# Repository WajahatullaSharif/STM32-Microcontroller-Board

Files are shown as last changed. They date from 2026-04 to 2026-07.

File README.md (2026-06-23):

# DeskNode-F4: Desk Automation Node

**DeskNode-F4** is an intelligent, high-current desk automation controller designed to eliminate phantom standby power and manage workspace environments dynamically. Built around the **STM32F407VGT6** microcontroller, the board intercepts host sleep/wake signals to automatically switch power rails for major workspace appliances and custom peripherals.

---

## 📊 System Architecture Block Diagram

```mermaid
graph TD
    %% Styling Configuration
    classDef mcu fill:#1b4d3e,stroke:#333,stroke-width:1.5px,color:#fff;
    classDef power fill:#d4af37,stroke:#333,stroke-width:1px,color:#000;
    classDef peripheral fill:#e1f5fe,stroke:#0288d1,stroke-width:1px,color:#000;
    classDef external fill:#f5f5f5,stroke:#616161,stroke-width:1px,color:#000;

    %% Central PCBA
    subgraph DeskNode_F4 [DeskNode-F4]
        DEBUGGER[STM32F103 Debugger]:::mcu
        MCU[STM32F407 MCU]:::mcu
        ETH[DP83826 PHY]:::peripheral
        LED_DRV[LED Driver ~5A]:::peripheral
        SENSE[Shunt + Op-Amp]:::peripheral
        RELAY_DRV[Relay Drivers]:::peripheral
    end

    %% Left-Side Power Inputs
    USB_OTG[OTG USB]:::power
    USB_DEB[Debug USB]:::power

    %% External Systems
    subgraph Laptop_Host [Laptop Host]
        LAPTOP[Laptop PC]:::external
    end

    subgraph AC_Loads [AC Mains Loads]
        LOADS[Monitors/Speakers/Other]:::external
    end

    %% Invisible spacer layout trick to push AC Loads down
    Laptop_Host ~~~ AC_Loads

    %% Left-Side Power Routing Layout
    USB_OTG -->|Power Input| MCU
    USB_DEB --> DEBUGGER
    DEBUGGER -->|Debug/Power| MCU
    
    %% Right-Side Power Routing Layout
    12V[12V Adaptor]:::power -->|DC Jack| LED_DRV

    %% Communication & Interface Links
    LAPTOP -->|Ethernet Link| ETH
    ETH <-->|RMII| MCU
    LAPTOP -->|USB CDC| MCU

    %% Output Paths
    MCU -->|PWM| LED_DRV -->|JST| STRIP[RGB LED Strip]:::external
    STRIP -->|Return| SENSE -->|Analog| MCU
    MCU -->|GPIO| RELAY_DRV -->|Control| AC_Loads
```

---

## 🛠️ System Architecture Overview

The core of the system is a custom **4-layer PCB** configured with a high-integrity stackup (**Signal / GND / Power / Signal**) to isolate sensitive analog paths from high-power switching transients.

### Onboard Hardware Features
* **Microcontroller:** STM32F407 ARM Cortex-M4 operating with a high-performance clock tree to coordinate networking, USB stacks, and deterministic control loops.
* **Onboard Debugger:** Integrated STM32F103-based DAP-Link. This permits single-cable firmware flashing and debugging directly over the `Debug USB` port without requiring external programmers.
* **Networking Subsystem:** DP83826 Physical Layer (PHY) transceiver linked to the MCU via a low-pin-count **RMII (Reduced Media Independent Interface)** bus. It provides a dedicated pipeline for sending continuous telemetry and log metrics to an external server or logging application.
* **Dual Power Inputs:** Flexible bus powering options allow the system logic to run entirely off the `Debugger USB (5V)` line or the primary `OTG USB (5V)` interface.

### Peripheral Control & Telemetry Loops
* **High-Current LED Driver:** A dedicated ~5A PWM driver stage capable of dimming and driving dense RGB LED strips utilized for monitor backlighting.
* **Current Telemetry (Shunt + Op-Amp):** A low-side inline current shunt paired with a precision operational amplifier provides analog current sensing feedback directly to the MCU's internal ADC. This ensures overload protection and active power calculation.
* **Relay Driver Array:** Low-voltage GPIO pins drive transistor/optocoupler stages to switch external heavy-duty AC relay modules safely.

---

## 🔄 Sequence of Operation

The system functions on a deterministic host-state monitoring loop via a virtual COM port over USB:

| Laptop State | USB CDC Pipeline | DeskNode-F4 Action |
| :--- | :--- | :--- |
| **Laptop Wakes** | Sends `"WAKE"` Token | 1. Latches AC Relays **ON** <br> 2. Ramps up Monitor LED Strip and Speakers |
| **Laptop Sleeps** | CDC Connection Drops | 1. Unlatches AC Relays **OFF** <br> 2. Cuts LED Strip Power |

### 1. The Wake Sequence (Power-On)
1. The host laptop wakes from standby or a sleep state.
2. An automation daemon running on the host detects the system state change and establishes a **USB CDC (Communications Device Class)** virtual serial connection.
3. The host transmits a configuration/activation token to the `DeskNode-F4` over USB.
4. The MCU immediately asserts its control GPIOs:
    * **Relay Output Pins** transition to high, latching the AC relay modules to deliver mains power simultaneously to **Monitor 1, Monitor 2, the Laptop Power Adaptor, and the Home Theatre System**.
    * **PWM Driver** initializes to ramp up the RGB backlight strip to the user's preferred brightness level via the onboard JST connection.

### 2. Continuous Monitoring State
* While active, the board uses the **DP83826 Ethernet PHY** to broadcast runtime diagnostics (uptime, temperature, and power drawing conditions) back to the laptop's logging software.
* The internal ADC continuously updates using the operational amplifier feedback loop across the shunt resistor to verify the current draw of the 5A LED string remains within a safe operating safe area (SOA).

### 3. The Sleep Sequence (Zero-Standby Power)
1. The host laptop enters a low-power sleep mode or is shut down.
2. The active USB CDC bus is dropped or broadcasts a graceful shutdown command packet.
3. Upon detecting the drop in the USB connection state, the `STM32F407` executes an emergency environment teardown:
    * All **GPIO Relay Driver lines** drop low, physically disconnecting the mains AC power lines. This drops the idle standby current consumption of the entire desk setup (monitors, sound systems, bricks) down to **absolute zero**.
    * The LED driver PWM is pulled to a 0% duty cycle, turning off the backlight completely.
    * The board drops into a low-power listening loop, drawing minimal parasitic power through the connected USB line until the next wake event.

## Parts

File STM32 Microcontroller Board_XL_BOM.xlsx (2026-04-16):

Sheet: BOM
Sr.No | Ref Des | Qty | Value | MPN | Make | Alternates/Substitutes | Make | Total Cost
1 | C1, C3, C9, C10
2 | C2, C4, C8
3 | C5
4 | C6, C7
5 | D1
6 | D2
7 | D3
8 | D4
9 | D5
10 | U1 | 1 | LOW COST ENET PHY INDUSTRIAL | DP83826IRHBR | Texas Instruments
11 | U2 | 3 | MOSFETs MOSFT 5.0A 29mOhm 30V 2.5V drv capable | IRLML6344TRPBF | Infineon Technologies
12 | R1, R5, R6, R14
13 | R2
14 | R3
15 | R4
16 | R7, R15
17 | R8, R16
18 | R9, R17
19 | R10, R18
20 | R11, R19
21 | R12, R20
22 | R13, R21, R23, R24
23 | R22
24 | R25, R26, R27, R28
25 | J1, J2
26 | J3
27 | X1 | 1 | CONN JACK 1PORT PCB | RJMG1S8008101BR | Amphenol ICC (Commercial Products)
28 | X2
 |  |  |  |  |  |  | Shipping cost
 |  |  |  |  |  |  | Total cost | ₹0.00

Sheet: Comparison
LED MOSFETs | Make | Vds | Id | Vgs(th) max | Rds ON @ 3.3V | Qc | Pd | Rja | Td On | Td Off | Tr | Tf | Cost
IRLML6344TRPBF | Infenion | 30V | 5A | 1.1V | 34mohm | 6.8nC | 1.3W | 100 C/W | 4.2ns | 22ns | 5.6ns | 9.1ns | ₹46
DMN3053L | Diodes | 30V | 4A | 1.4V | 52mohm | 7.3nC | 0.76W | 100 C/W | 2ns | 152ns | 5.5ns | 32ns | ₹50
DMN3065LW-7 | Diodes | 30V | 4A | 1.5V | 75mohm | 5.5nC | 0.77W | 162 C/W | 1.9ns | 10.3ns | 1.6ns | 2ns | ₹43
DMG3402L-7 | Diodes | 30V | 4A | 1.4V | 75mohm | 5.5nC | 1.4W | 90 C/W | 1.9ns | 10.3ns | 1.6ns | 2ns | ₹21
DMN3150L-7 | Diodes | 30V | 3.8A | 1.4V | 90mohm | 8.2nC | 1.4W | 90 C/W | 1.14ns | 15ns | 3.5ns | 3.3ns | ₹38

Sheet: Requirements
Current sensing for LED Drivers with internal ADC |  |  | LED strip connector
Use OPAMP TLV9001 with non inverting amplifier config
Shunt resistor | 20mohm, >=3W(5W preferred)
Current Limit | 5A | Vshunt = 100mV
Fault Current | 10A | Vshunt = 200mV
Map | 0 to 10A | 0 to 2V
Gain | 10x
Filtering | 2nd order LPF
Values | R=2.2kohm, C=0.47nF
230V Power Control
Use ULN2803CDWR
COM->VDD for SSR, NC for Mech relay
12V adaptor for LED and relay control
Board Power |  |  | STLINK_VBUS ──|>|──┐
Diode OR USB FS and Debugger USB Vbus |  |  | +5V_BOARD ── LDO ── 3V3 (STM32)
Use low-Vf Schottky: SS14 / PMEG2010 / BAT54S (dual) - ≥1 A rating (USB + LED logic load) |  |  | USB_FS_VBUS ──|>|──┘
12V only for relays and LED |  |  | EXT_5V In/ Out ──────┘
OTG_FS_PowerSwitchOn (PH5)
Leave PH5 unconnected. Or pull it down weakly |  |  | 12V_ADAPTER ────────────► LED MOSFETs
Do NOT connect PA9 (VBUS sense) through diode. Connect directly |  |  | └─────────────► SSR Relay board

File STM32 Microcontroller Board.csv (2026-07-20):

Reference | Qty | Value | Description | Footprint | MPN
C1,C4,C7,C8,C9,C10,C11,C12,C13,C16,C17,C19,C25,C26,C29,C30,C31,C33,C35,C42,C50 | 21 | 0.1uF | CAP CER 0.1UF 10V X7R 0402 | Capacitor_SMD:C_0402_1005Metric | GRM155R71A104KA01D
C2,C5 | 2 | 2.2uF | CAP CER 2.2UF 10V X7R 0603 | Capacitor_SMD:C_0603_1608Metric | CL10B225KP8NNNC
C3,C6,C27,C36,C43,C51 | 6 | 1uF | CAP CER 1UF 10V X7R 0603 | Capacitor_SMD:C_0603_1608Metric | CL10B105KP8NNNC
C14,C28 | 2 | 4.7uF | CAP CER 4.7UF 16V X7R 0805 | Capacitor_SMD:C_0805_2012Metric | GRM21BR71C475KE51L
C15,C20 | 2 | 10uF | CAP CER 10UF 16V X7R 0805 | Capacitor_SMD:C_0805_2012Metric | CL21B106KOQNNNE
C18 | 1 | 1nF | CAP CER 1000PF 16V X7R 0603 | Capacitor_SMD:C_0603_1608Metric | C0603C102K4RACTU
C21,C24,C34,C41 | 4 | 10nF | CAP CER 10000PF 25V X7R 0402 | Capacitor_SMD:C_0402_1005Metric | GRM155R71E103KA01D
C22,C23,C38,C39 | 4 | 27pF | CAP CER 27PF 50V C0G/NP0 0603 | Capacitor_SMD:C_0603_1608Metric | CL10C270JB8NNNC
C32 | 1 | 1nF | CAP CER 1000PF 2KV X7R 1206 | Capacitor_SMD:C_1206_3216Metric | CC1206KKX7RDBB102
C37 | 1 | 2nF | CAP CER 2000PF 50V C0G/NP0 0603 | Capacitor_SMD:C_0603_1608Metric | GRM1885C1H202JA01D
C40,C44 | 2 | 10uF | CAP CER 10UF 10V X7R 0805 | Capacitor_SMD:C_0805_2012Metric | GRM21BR71A106KA73L
C45 | 1 | 1uF | CAP CER 1UF 50V X7R 0603 | Capacitor_SMD:C_0603_1608Metric | CC0603KRX7R9BB105
C46 | 1 | 0.1uF | CAP CER 0.1UF 50V X7R 0603 | Capacitor_SMD:C_0603_1608Metric | C0603C104K5RACTU
C47 | 1 | 680uF | CAP ALUM 680UF 20% 25V SMD | footprints:UCL1E681MNL1GS | UCL1E681MNL1GS
C48,C49 | 2 | 0.47uF | CAP CER 0.47UF 25V X7R 0603 | Capacitor_SMD:C_0603_1608Metric | CL10B474KA8NFNC
D1 | 1 | 3.3V | 300mW Zener Diode, SOD-323F | Diode_SMD:D_SOD-323F | MM3Z3V3T1G
D2,D3,D9 | 3 | Green LED | LED GREEN CLEAR CHIP SMD | LED_SMD:LED_0805_2012Metric | APT2012CGCK
D4,D13 | 2 | Blue LED | LED BLUE CLEAR 2SMD | LED_SMD:LED_0805_2012Metric | APT2012LVBC/D
D5,D11 | 2 | Yellow LED | LED YELLOW CLEAR CHIP SMD | LED_SMD:LED_0805_2012Metric | APT2012SYCK
D6 | 1 | Red LED | LED RED CLEAR CHIP SMD | LED_SMD:LED_0805_2012Metric | APT2012SURCK
D7 | 1 | LTST-E682KRKGWT | LED GREEN/RED DIFFUSED 4PLCC SMD | footprints:LTSTE683RGBW | LTST-E682KRKGWT
D8,D14 | 2 | LSM115JE3 | DIODE SCHOTTKY 15V 1A DO214BA | Diode_SMD:D_SMB | LSM115JE3-TR13
D10 | 1 | SP1004U-ULC-04UTG | ESD Protection Diodes / TVS Diodes 5V .2pF 20kV 4CH | footprints:ESD8104MUTAG | SP1004U-ULC-04UTG
D12 | 1 | SMBJ15CA | TVS DIODE 15VWM 24.4VC DO214AA | footprints:SMBJ15A | SMBJ15CA
D15 | 1 | SMBJ15A | Littelfuse SMBJ15A, Uni-Directional TVS Diode, 600W, 2-Pin DO-214AA | footprints:SMBJ15A
D16,D17,D18 | 3 | SMF15A | 200W unidirectional Transil Transient Voltage Suppressor, 15Vrwm, SMF | Diode_SMD:D_SMF | SMF15A
F1,F3 | 2 | Polyfuse | PTC RESET FUSE 6V 750MA 1206 | Fuse:Fuse_1206_3216Metric | NANOSMDC075F-2
F2 | 1 | Polyfuse | PTC RESET FUSE 6.0A 16V 2920 | footprints:Fuse_2920_7451Metric | 2920L600/16MR
FB1,FB2 | 2 | FerriteBead | FERRITE BEAD 600 OHM 0603 1LN | Inductor_SMD:L_0603_1608Metric | MPZ1608S601ATA00
H1,H2,H3,H4 | 4 | MountingHole | Mounting Hole without connection | MountingHole:MountingHole_3.2mm_M3_Pad
J1 | 1 | F407 SWD | Generic connector, single row, 01x06, script generated | Connector_PinHeader_2.54mm:PinHeader_1x06_P2.54mm_Vertical
J2 | 1 | GPIO | Generic connector, double row, 02x09, odd/even pin numbering scheme (row 1 odd numbers, row 2 even numbers), script generated (kicad-library-utils/schlib/autogen/connector/) | Connector_PinHeader_2.54mm:PinHeader_2x09_P2.54mm_Vertical
J3 | 1 | Conn_01x02_Pin | Generic connector, single row, 01x02, script generated | Connector_PinHeader_2.54mm:PinHeader_1x02_P2.54mm_Vertical
J4 | 1 | F103 SWD | Generic connector, single row, 01x06, script generated | Connector_PinHeader_2.54mm:PinHeader_1x06_P2.54mm_Vertical
J5,J10 | 2 | USB_B_Micro | MICRO B SKT, BOTTOM-SMT, R/A, 30 | footprints:USB_Micro-B_GCT_USB3076-30-A | USB3076-30-A
J6 | 1 | Ethernet | CONN JACK 1PORT PCB | footprints:AMPHENOL_RJMG1S8008101BR | RJMG1S8008101
J7 | 1 | 12V IN | DC Barrel Jack with an internal switch | Connector_BarrelJack:BarrelJack_Horizontal
J8 | 1 | 12V RGB LED | CONN HEADER R/A 4POS 3.96MM | footprints:B4PS-VH | B4PS-VH(LF)(SN)
J9 | 1 | Relay IO | Generic connector, double row, 02x05, odd/even pin numbering scheme (row 1 odd numbers, row 2 even numbers), script generated (kicad-library-utils/schlib/autogen/connector/) | Connector_PinHeader_2.54mm:PinHeader_2x05_P2.54mm_Vertical
Q1 | 1 | PMOS | MOSFET P-CH 30V 13A 8SOIC | Package_SO:SOIC-8_5.3x5.3mm_P1.27mm | FDS6679AZ
Q2,Q3,Q4 | 3 | NMOS | MOSFET N-CH 30V 5A MICRO3/SOT23 | Package_TO_SOT_SMD:SOT-23 | IRLML6344TRPBF
R1,R2,R4,R7,R25,R28,R32,R34,R36,R37,R39,R40,R42,R56,R57,R58,R59,R60,R61,R62,R63,R64 | 22 | 10k | RES 10K OHM 1% 1/10W 0603 | Resistor_SMD:R_0603_1608Metric | RC0603FR-0710KL
R3,R6,R10 | 3 | 330R | RES 330 OHM 1% 1/10W 0603 | Resistor_SMD:R_0603_1608Metric | RC0603FR-07330RL
R5,R46,R50,R53 | 4 | 100R | RES 100 OHM 1% 1/10W 0603 | Resistor_SMD:R_0603_1608Metric | RC0603FR-07100RL
R8 | 1 | 33k | RES 33K OHM 1% 1/10W 0603 | Resistor_SMD:R_0603_1608Metric | RC0603FR-0733KL
R9 | 1 | 82k | RES 82K OHM 1% 1/10W 0603 | Resistor_SMD:R_0603_1608Metric | RC0603FR-0782KL
R11,R21,R22 | 3 | 680R | RES 680 OHM 1% 1/10W 0603 | Resistor_SMD:R_0603_1608Metric | RC0603FR-07680RL
R12,R14,R30,R67 | 4 | 1k | RES 1K OHM 1% 1/10W 0603 | Resistor_SMD:R_0603_1608Metric | RC0603FR-071KL
R13,R26,R31 | 3 | 1.5k | RES 1.5K OHM 1% 1/10W 0603 | Resistor_SMD:R_0603_1608Metric | RC0603FR-071K5L
R15,R16 | 2 | 4K7 | RES 4.7K OHM 1% 1/10W 0603 | Resistor_SMD:R_0603_1608Metric | RC0603FR-074K7L
R17,R18,R19,R20,R27,R43,R44,R47,R52,R54,R68 | 11 | 100k | RES 100K OHM 1% 1/10W 0603 | Resistor_SMD:R_0603_1608Metric | RC0603FR-07100KL
R23,R24,R65,R66 | 4 | 22R | RES 22 OHM 1% 1/10W 0603 | Resistor_SMD:R_0603_1608Metric | RC0603FR-0722RL
R29 | 1 | 1M | RES 1M OHM 1% 1/10W 0603 | Resistor_SMD:R_0603_1608Metric | RC0603FR-071ML
R33 | 1 | 6.49k | RES 6.49K OHM 1% 1/10W 0603 | Resistor_SMD:R_0603_1608Metric | RC0603FR-076K49L
R35,R38,R41 | 3 | 2.49k | RES 2.49K OHM 1% 1/10W 0603 | Resistor_SMD:R_0603_1608Metric | RC0603FR-072K49L
R45 | 1 | 22.1k | RES 22.1K OHM 1% 1/10W 0603 | Resistor_SMD:R_0603_1608Metric | RC0603FR-0722K1L
R48 | 1 | 20m | RES 0.02 OHM 1% 3W 2512 | Resistor_SMD:R_2512_6332Metric | CRA2512-FZ-R020ELF
R49,R51 | 2 | 2.2k | RES 2.2K OHM 1% 1/10W 0603 | Resistor_SMD:R_0603_1608Metric | RC0603FR-072K2L
R55 | 1 | 90.9k | RES 90.9K OHM 1% 1/10W 0603 | Resistor_SMD:R_0603_1608Metric | RC0603FR-0790K9L
R69,R70,R71 | 3 | 0R | RES 0 OHM JUMPER 1/10W 0603 | Resistor_SMD:R_0603_1608Metric | RC0603JR-070RL
SW1,SW2,SW3,SW4,SW5,SW6 | 6 | SW_Push | SWITCH TACTILE SPST-NO 0.05A 12V | Button_Switch_SMD:SW_SPST_PTS645Sx43SMTR92 | PTS645SK50SMTR92 LFS
TP1 | 1 | BOOT0 | test point | TestPoint:TestPoint_Pad_D1.0mm
TP2 | 1 | NRST | test point | TestPoint:TestPoint_Pad_D1.0mm
TP3,TP4,TP5,TP7,TP8,TP9 | 6 | TestPoint | PC TEST POINT MINIATURE BLACK,test point | TestPoint:TestPoint_Keystone_5000-5004_Miniature | 5001
TP6 | 1 | RMII_REF_CLK | test point | TestPoint:TestPoint_Pad_D1.0mm
U1 | 1 | STM32F407VGTx | IC MCU 32BIT 1MB FLASH 100LQFP | Package_QFP:LQFP-100_14x14mm_P0.5mm | STM32F407VGT6
U2 | 1 | MCP1825S-3302E/EB | IC REG LINEAR 3.3V 500MA DDPAK-3 | footprints:DDPAK3_MC_MCH-L | MCP1825S-3302E/EB
U3 | 1 | STM32F103C8T6 | IC MCU 32BIT 64KB FLASH 48LQFP | footprints:QFP50P900X900X160-48N | STM32F103C8T6
U4,U8 | 2 | USBLC6-2 | TVS DIODE 5VWM 15VC SOT236 | Package_TO_SOT_SMD:SOT-23-6 | USBLC6-2SC6
U5 | 1 | DP83826IRHBR | LOW COST ENET PHY INDUSTRIAL | footprints:QFN50P500X500X100-33N-D | DP83826IRHBR
U6 | 1 | TLV9001TIDCKR | Low-power, Rail-to-Rail, 1MHz Operational Amplifier, SOT-353 | Package_TO_SOT_SMD:SOT-353_SC-70-5 | TLV9001TIDCKR
U7 | 1 | ULN2803CDWR | Bipolar (BJT) Transistor Array 8 NPN Darlington 50V 500mA Surface Mount 20-SOIC | footprints:ULN2803CDWR | ULN2803CDWR
Y1 | 1 | 8MHz | Two pin crystal | Crystal:Crystal_HC49-4H_Vertical | ECS-80-18-5PX-TR
Y2 | 1 | 25MHz | Four pin crystal, GND on pins 2 and 4 | footprints:ECS2501836B2CTYTR | ECS-250-18-36B2-CTY-TR

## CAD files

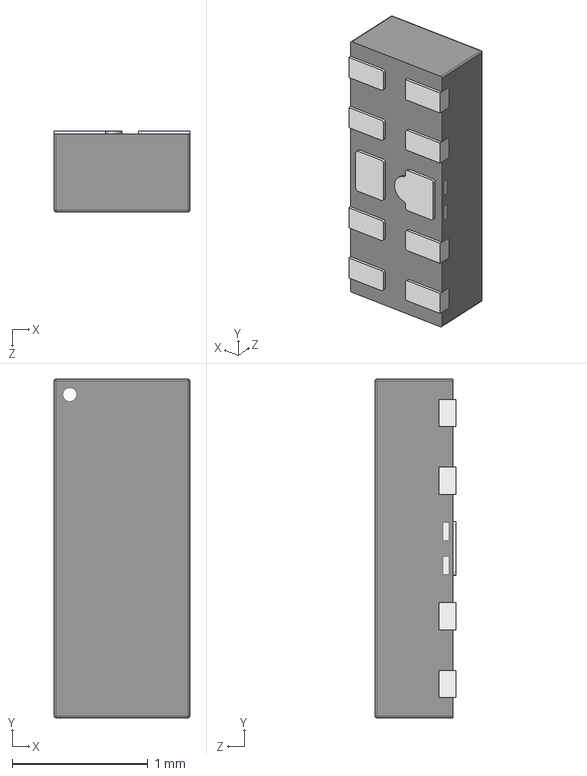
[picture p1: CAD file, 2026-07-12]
3dmodels/SP1004U-ULC-04UTG.stp
1.00 x 2.50 x 0.6 mm

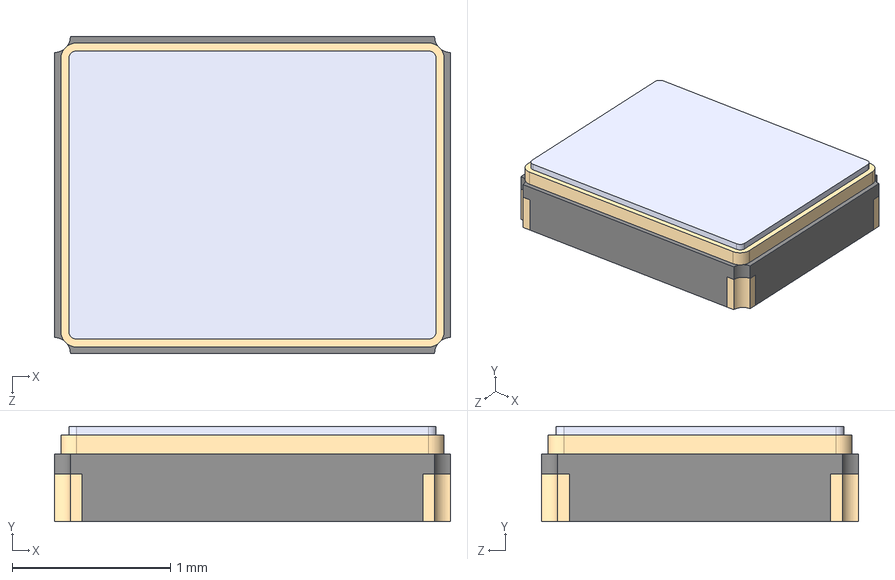
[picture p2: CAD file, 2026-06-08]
3dmodels/ECS-250-18-36B2-CTY-TR.stp
2.50 x 0.6 x 2.00 mm

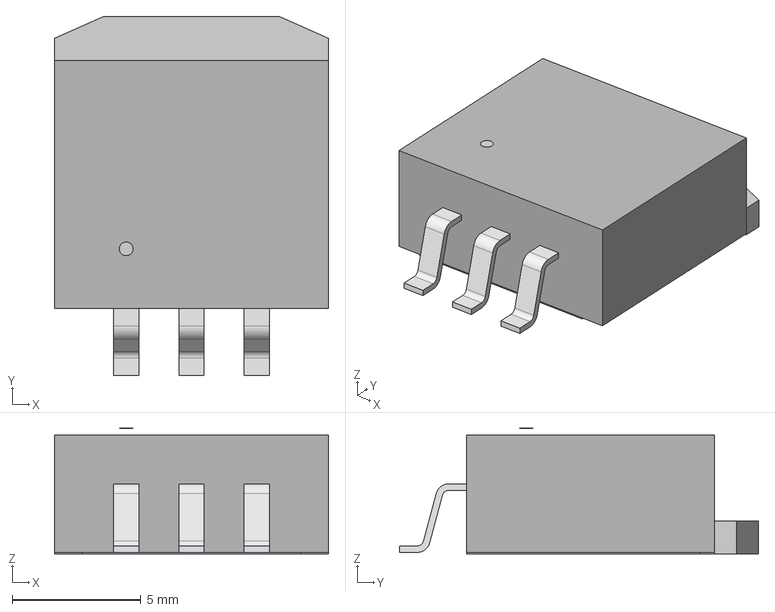
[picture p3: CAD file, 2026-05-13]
3dmodels/MCP1825S-3302EEB.step
10.7 x 14.0 x 4.88 mm

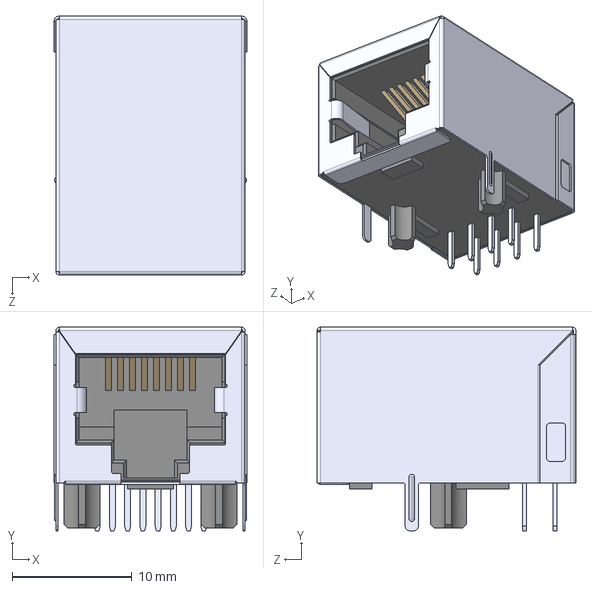
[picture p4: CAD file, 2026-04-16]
3dmodels/RJMG1S8008101BR--3DModel-STEP-418109.STEP
16.1 x 17.0 x 21.6 mm

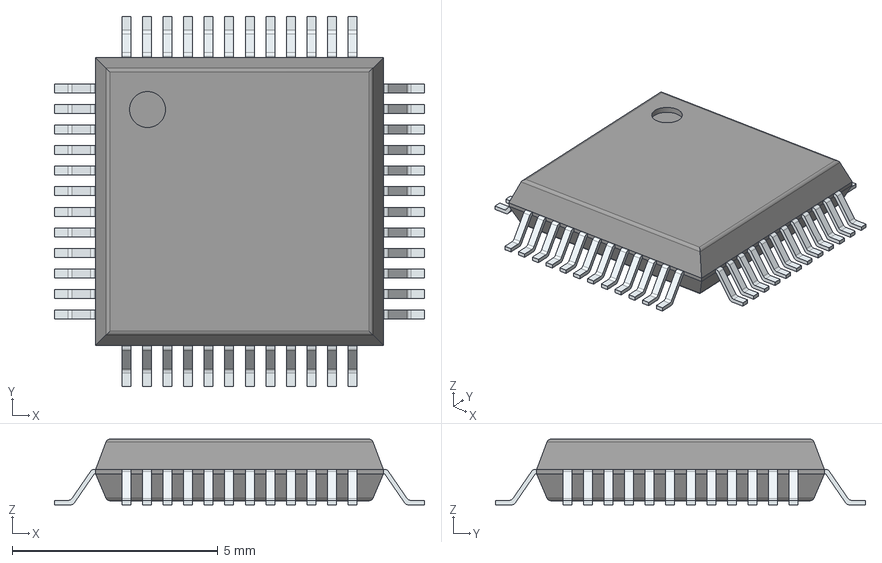
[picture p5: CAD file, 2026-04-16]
3dmodels/STM32F103C8T6.stp
9.00 x 9.00 x 1.60 mm
PinsArrayLR
PinsArrayTB

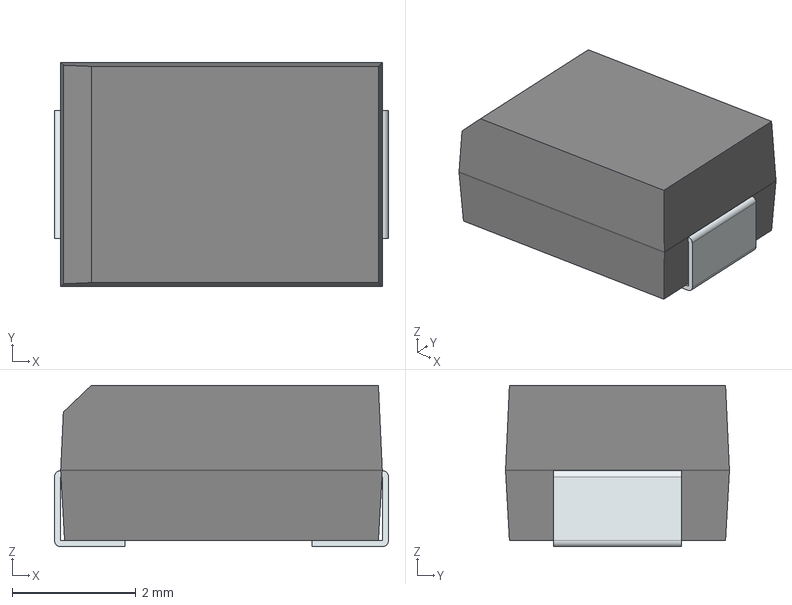
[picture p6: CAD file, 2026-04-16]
3dmodels/SMBJ15A.stp
5.40 x 3.62 x 2.61 mm
FilletPin1
FilletPin2

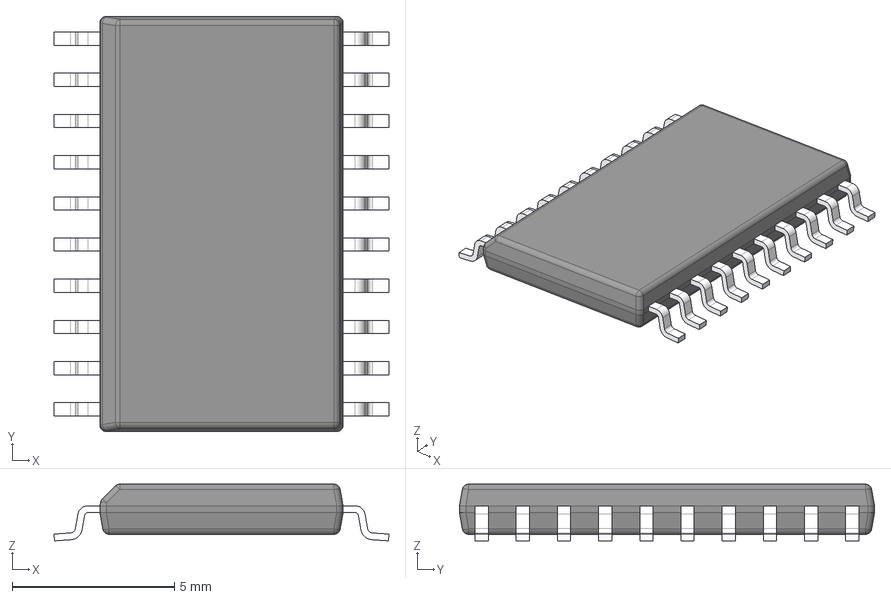
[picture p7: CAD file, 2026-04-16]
3dmodels/ULN2803CDWR.stp
10.3 x 12.8 x 1.75 mm
BODY-SO
LEAD-SO x 20
PIN1-ID

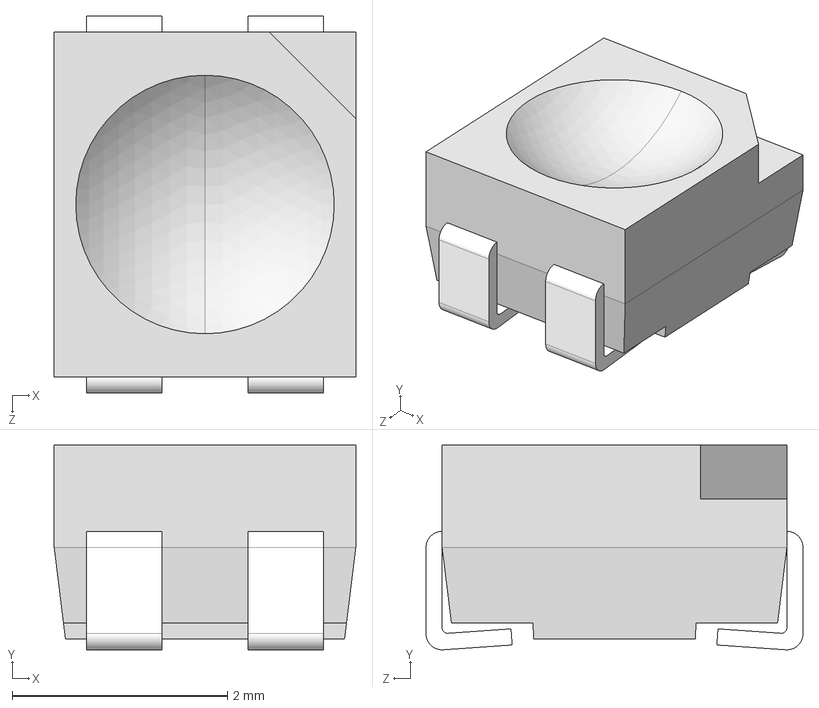
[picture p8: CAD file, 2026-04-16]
3dmodels/LTST-E682KRKGWT.stp
2.80 x 1.90 x 3.50 mm

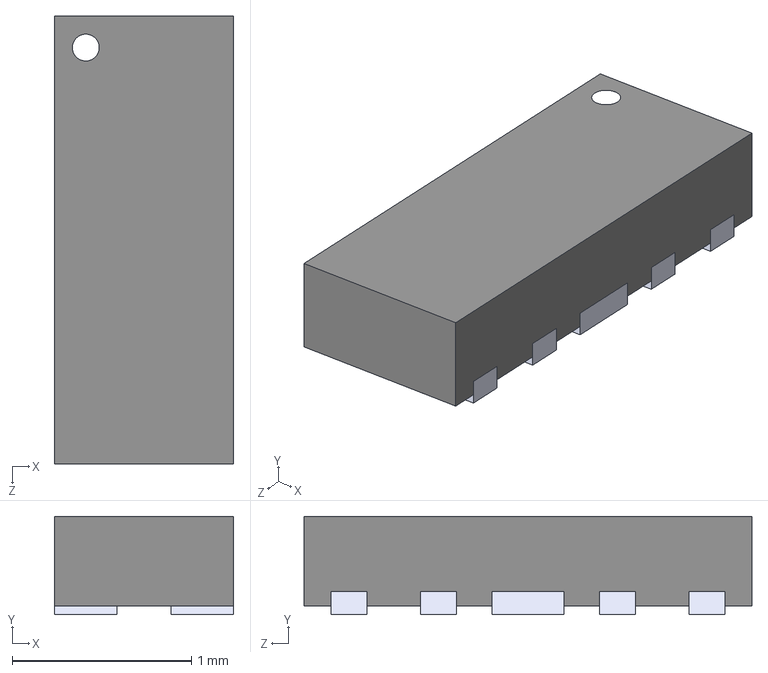
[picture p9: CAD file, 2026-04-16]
3dmodels/ESD7104MUTAG.STEP
1.00 x 0.55 x 2.50 mm

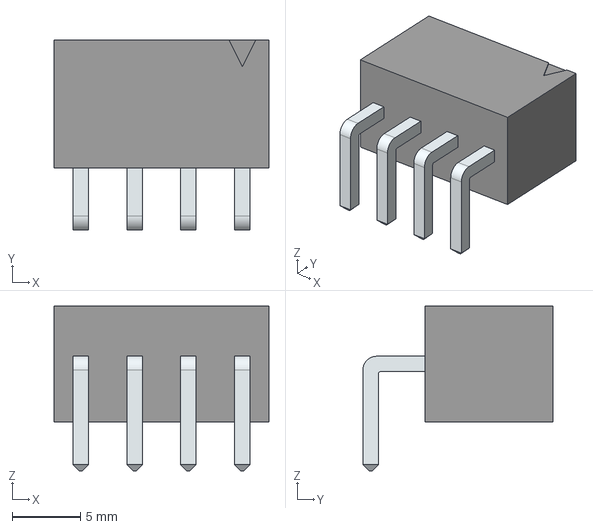
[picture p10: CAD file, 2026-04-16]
3dmodels/B4PS-VH_LF__SN_.stp
15.8 x 14.0 x 12.1 mm
LeadsArray

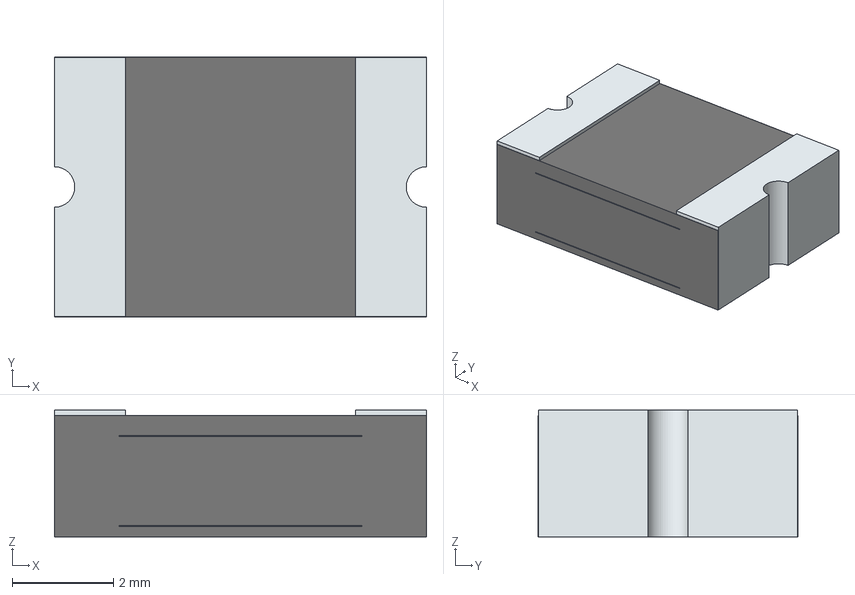
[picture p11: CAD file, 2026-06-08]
3dmodels/2920L600_24SLER.stp
7.35 x 5.14 x 2.50 mm
Rect6
Rect7
solidBody
Terminal

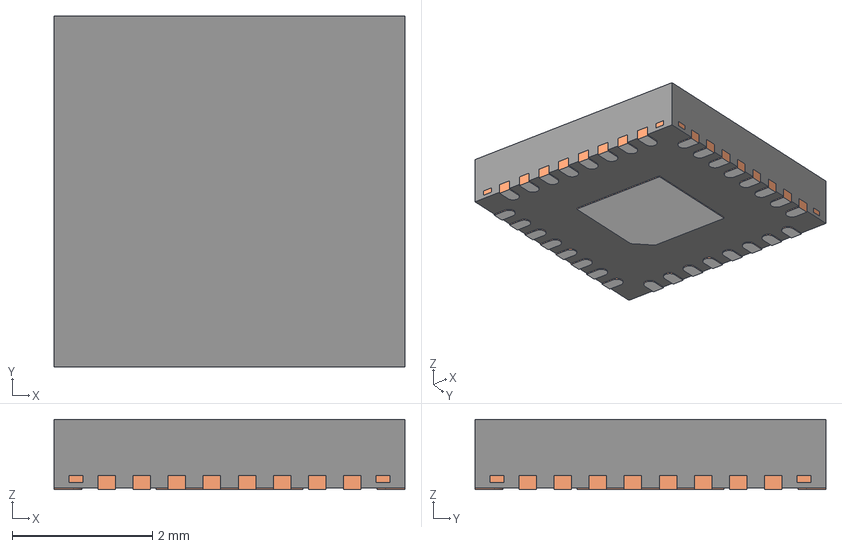
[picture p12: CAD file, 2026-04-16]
3dmodels/DP83826IRHBR.stp
5.00 x 5.00 x 1.00 mm
BODY-QFN
FRAME-RHB0032M
PIN1-ID

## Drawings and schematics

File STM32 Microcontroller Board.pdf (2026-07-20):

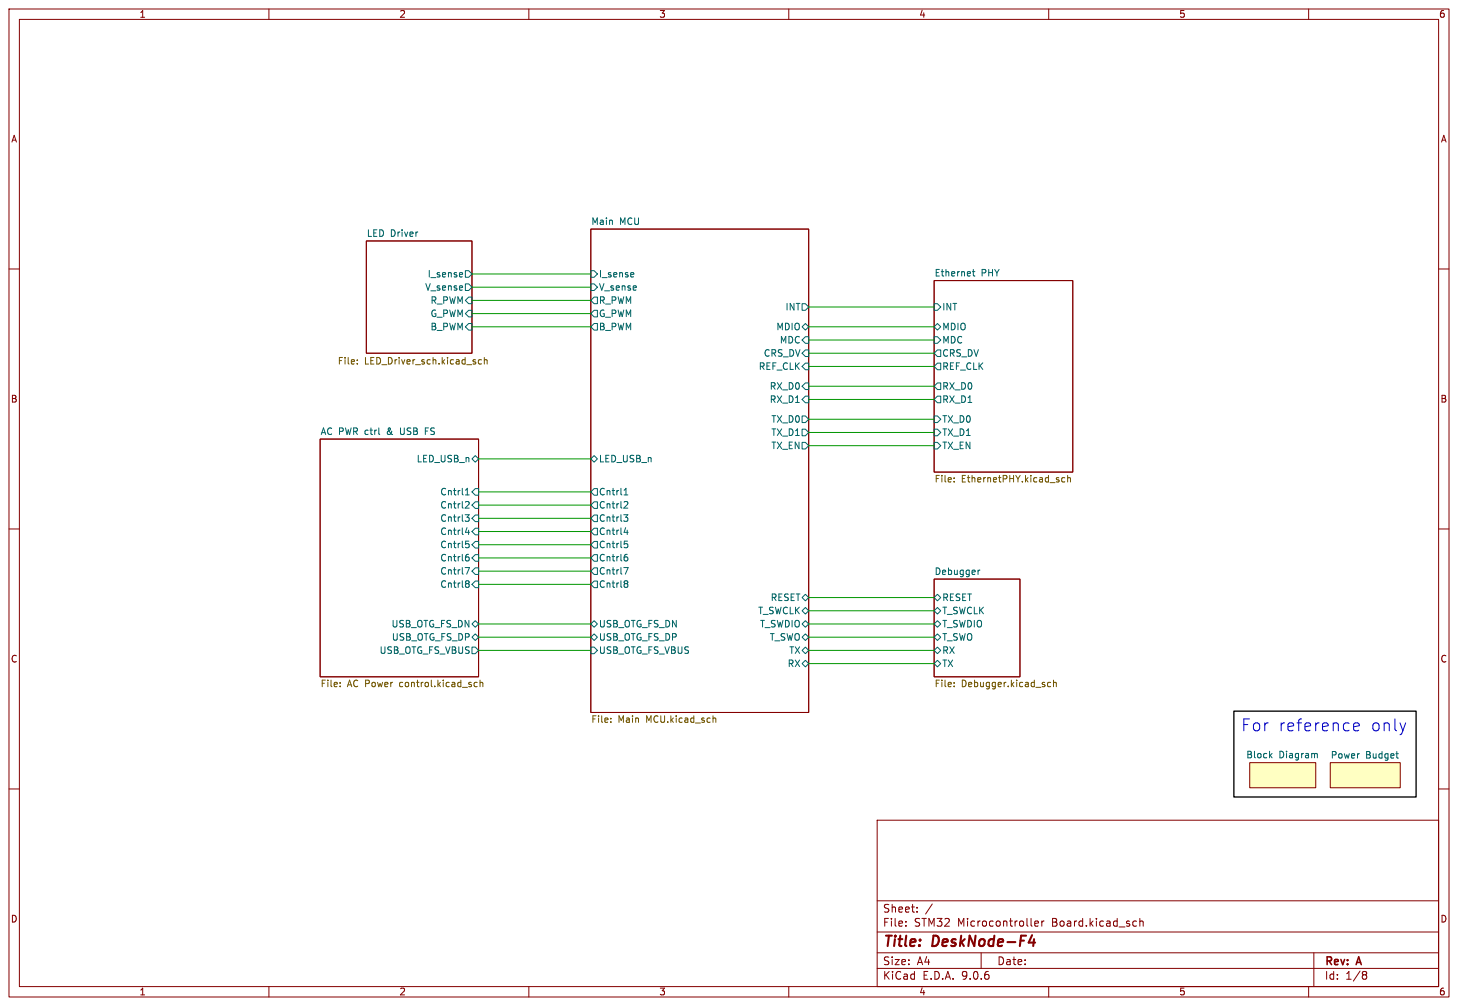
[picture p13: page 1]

AC PWR ctrl & USB FS

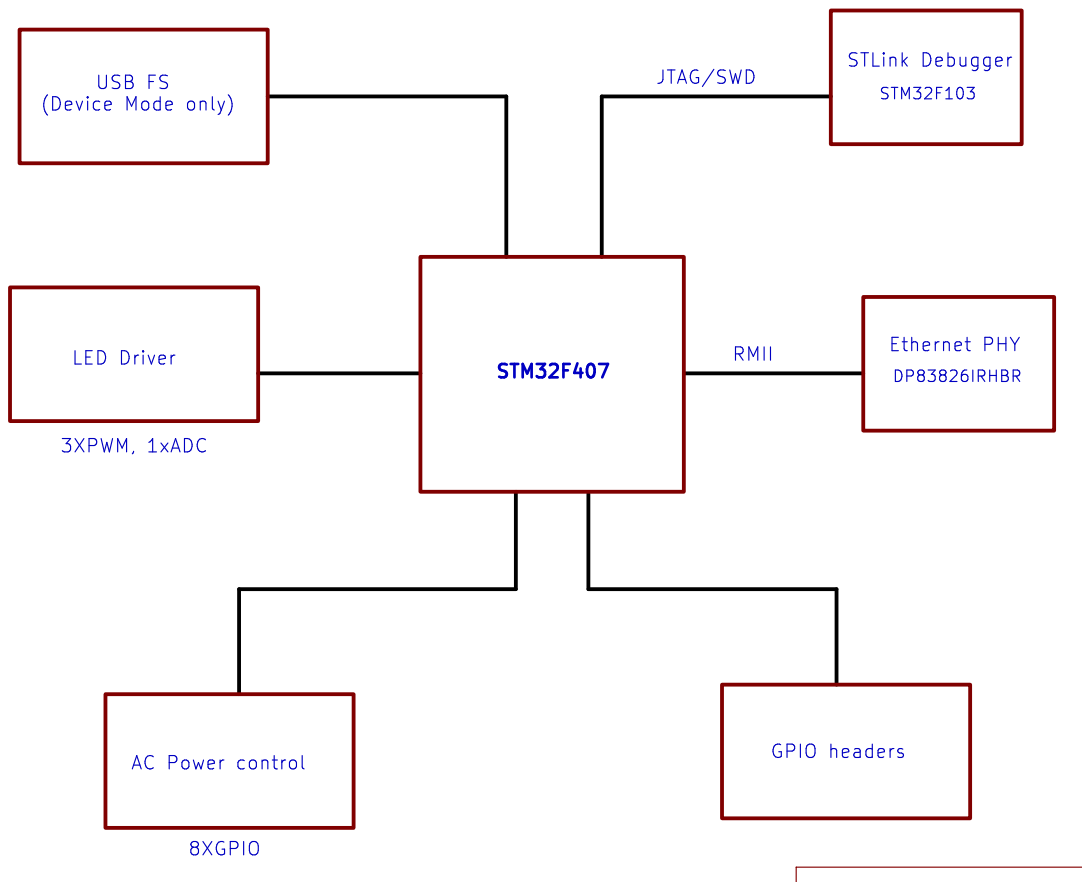
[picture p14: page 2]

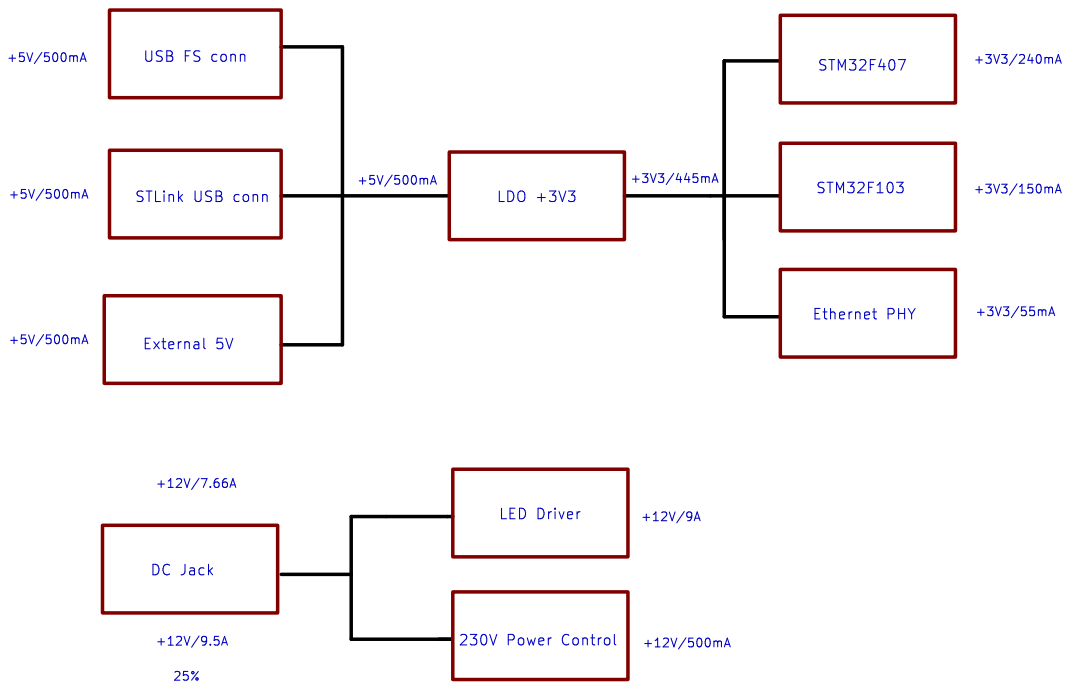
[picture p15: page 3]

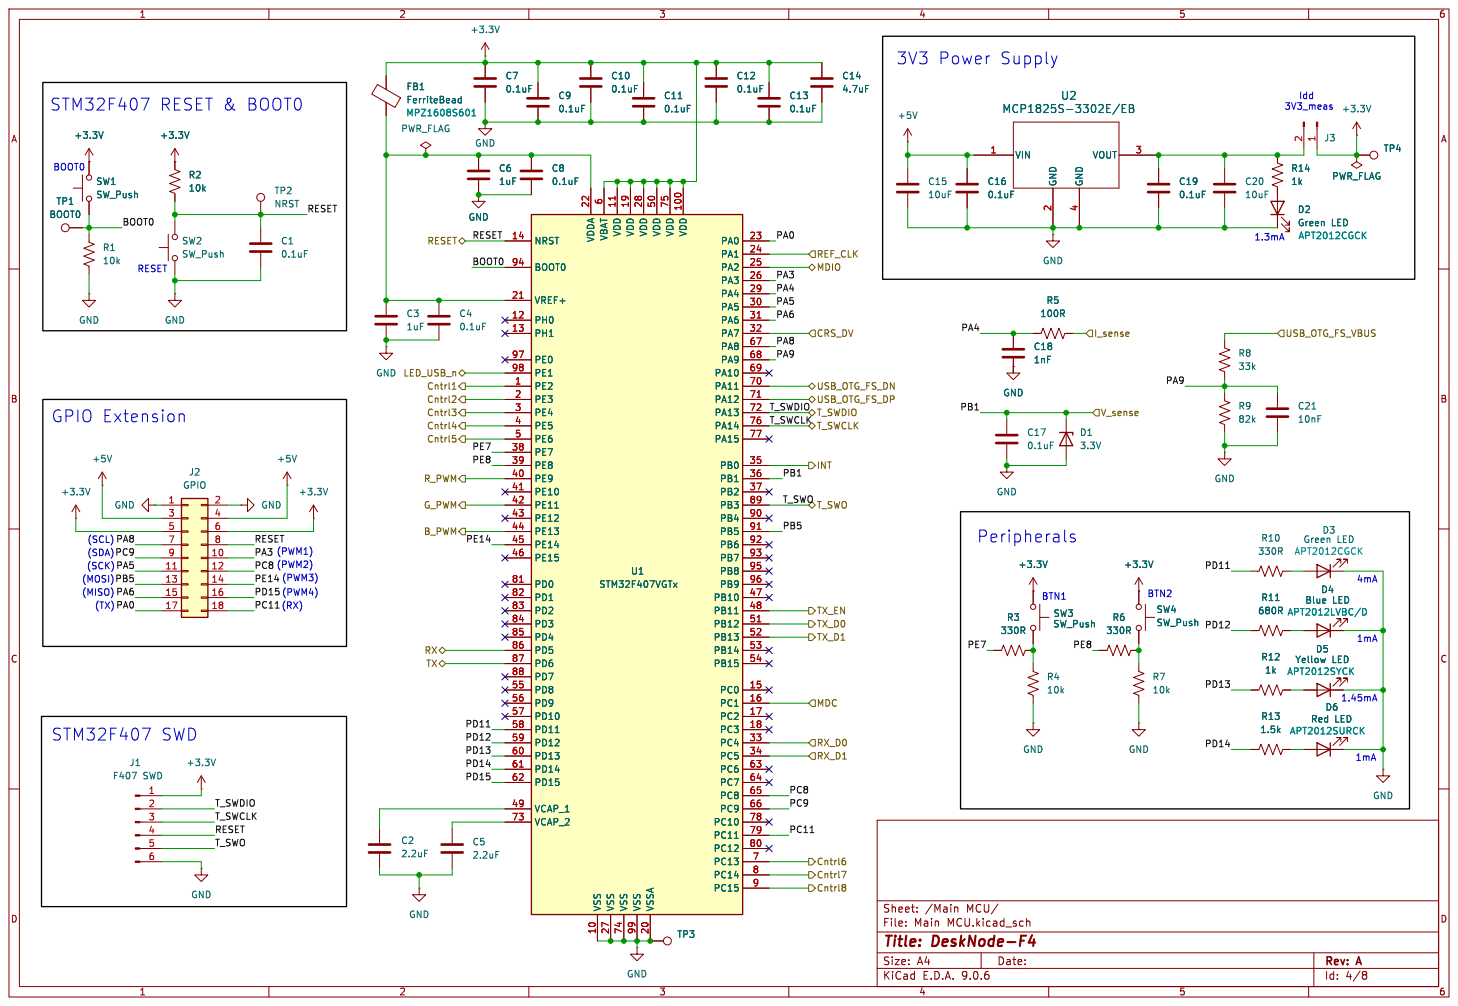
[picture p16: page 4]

6 VSS 27 VDD 11 VSS 74 VDD 19 VSS 99 VDD 28 VSSA 20 VDD 50 VDD 75 VDD 100 PA0 23 PA1 24 PA2 25 PA3 26 PA4 29 PA5 30 PA6 31 PA7 32 PA8 67 PA9 68 PA10 69 PA11 70 PA12 71 PA13 72 PA14 76 PA15 77 PB0 35 PB1 36 PB2 37 PB3 89 PB4 90 PB5 91 PB6 92 PB7 93 PB8 95 PB9 96 PB10 47 PB11 48 PB12 51 PB13 52 PB14 53 PB15 54 PC0 15 PC1 16 PC2 17 PC3 18 PC4 33 PC5 34 PC6 63 PC7 64 PC8 65 PC9 66 PC10 78 PC11 79 PC12 80 PC13 7 PC14 8 PC15 9 U1 STM32F407VGTx C6
1uF GND
Cntrl4 RESET Cntrl3 TX

6 VSS 27 VDD 11 VSS 74 VDD 19 VSS 99 VDD 28 VSSA 20 VDD 50 VDD 75 VDD 100 PA0 23 PA1 24 PA2 25 PA3 26 PA4 29 PA5 30 PA6 31 PA7 32 PA8 67 PA9 68 PA10 69 PA11 70 PA12 71 PA13 72 PA14 76 PA15 77 PB0 35 PB1 36 PB2 37 PB3 89 PB4 90 PB5 91 PB6 92 PB7 93 PB8 95 PB9 96 PB10 47 PB11 48 PB12 51 PB13 52 PB14 53 PB15 54 PC0 15 PC1 16 PC2 17 PC3 18 PC4 33 PC5 34 PC6 63 PC7 64 PC8 65 PC9 66 PC10 78 PC11 79 PC12 80 PC13 7 PC14 8 PC15 9 TP3

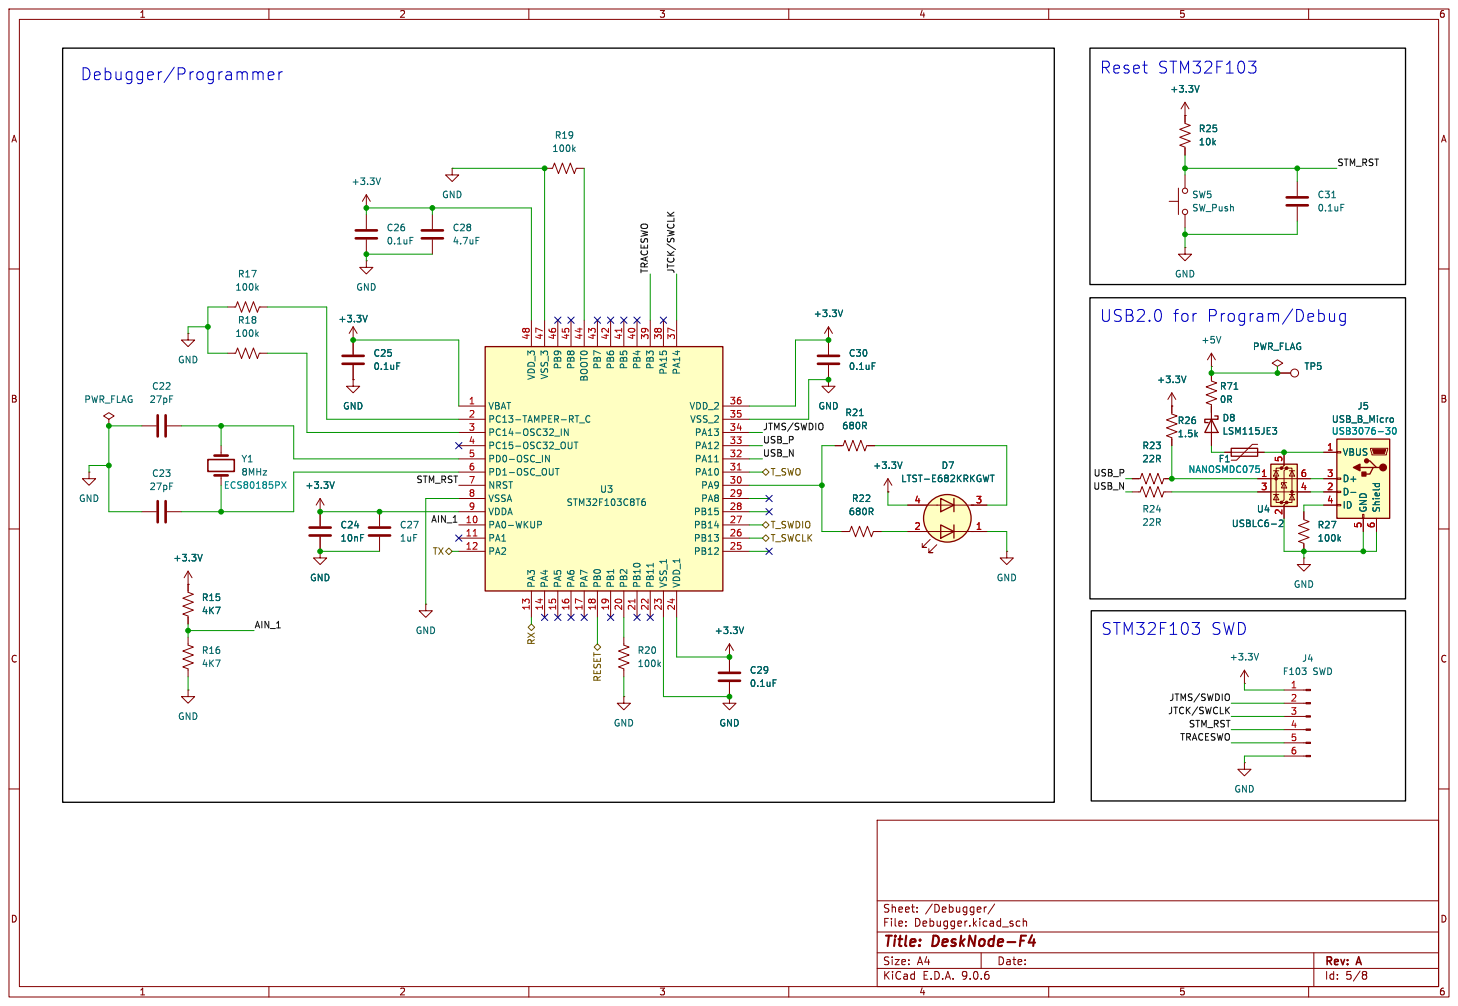
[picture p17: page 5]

File: Debugger.kicad_sch Sheet: /Debugger/
Id: 5/8 Title: DeskNode-F4

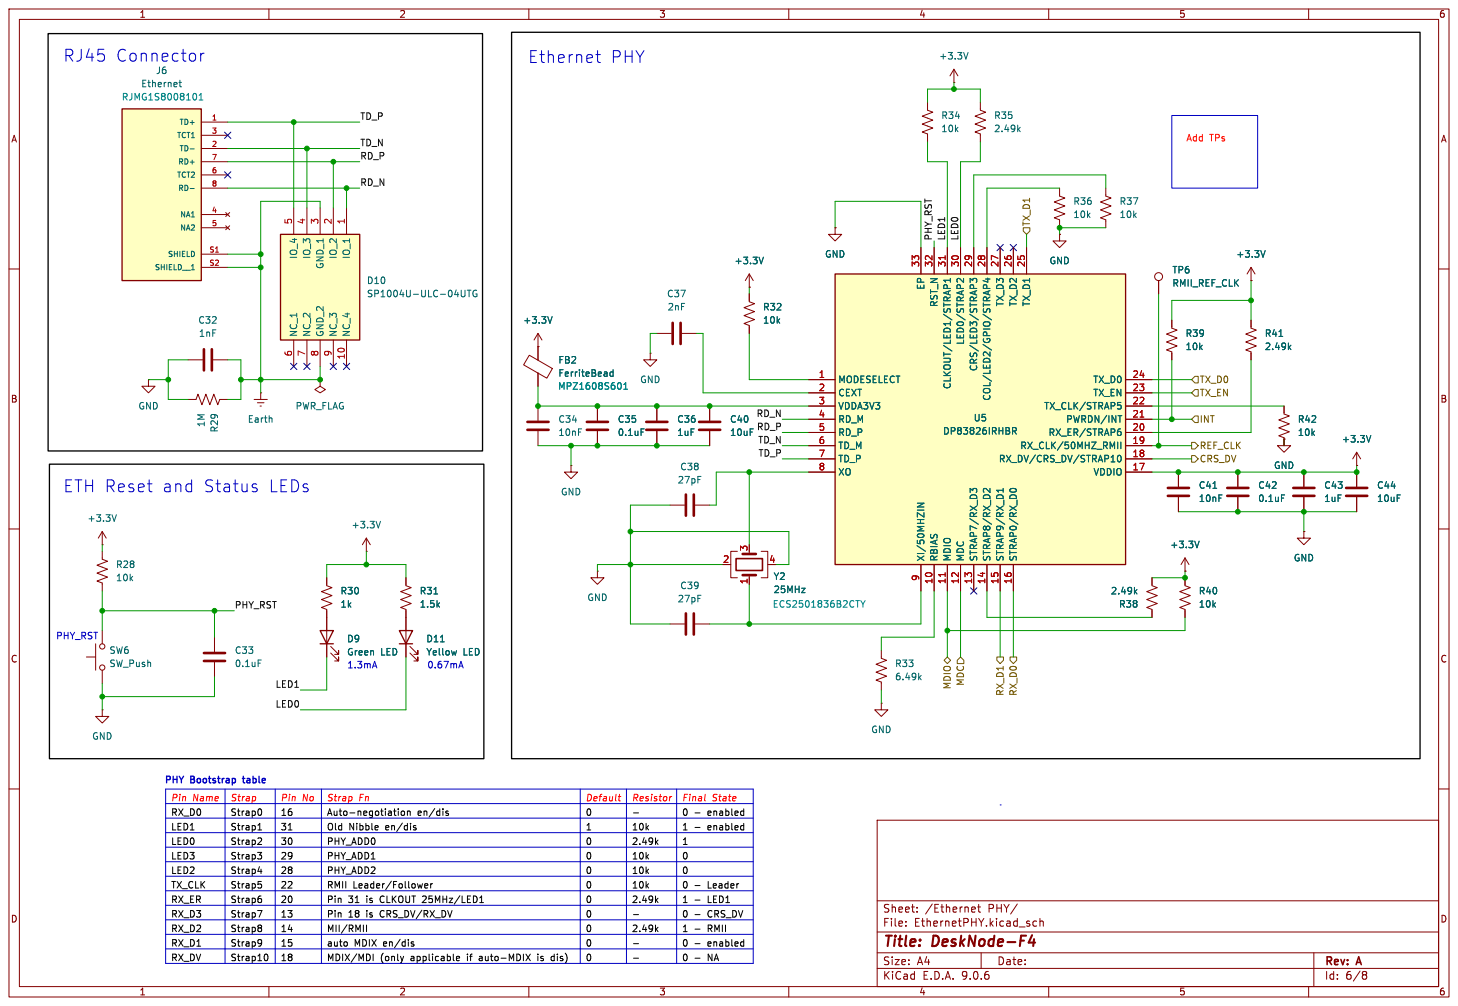
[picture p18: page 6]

9 RST_N 32 RBIAS 10 CLKOUT/LED1/STRAP1 31 MDIO 11 LED0/STRAP2 30 MDC 12 CRS/LED3/STRAP3 29 STRAP7/RX_D3 13 COL/LED2/GPIO/STRAP4 28 STRAP8/RX_D2 14 TX_D3 27 STRAP9/RX_D1 15 TX_D2 26 STRAP0/RX_D0 16 TX_D1 25 TX_D0 24 TX_EN 23 TX_CLK/STRAP5 22 PWRDN/INT 21 RX_ER/STRAP6 20 RX_CLK/50MHZ_RMII 19 RX_DV/CRS_DV/STRAP10 18 VDDIO 17 U5 DP83826IRHBR GND

9 RST_N 32 RBIAS 10 CLKOUT/LED1/STRAP1 31 MDIO 11 LED0/STRAP2 30 MDC 12 CRS/LED3/STRAP3 29 STRAP7/RX_D3 13 COL/LED2/GPIO/STRAP4 28 STRAP8/RX_D2 14 TX_D3 27 STRAP9/RX_D1 15 TX_D2 26 STRAP0/RX_D0 16 TX_D1 25 TX_D0 24 TX_EN 23 TX_CLK/STRAP5 22 PWRDN/INT 21 RX_ER/STRAP6 20 RX_CLK/50MHZ_RMII 19 RX_DV/CRS_DV/STRAP10 18 VDDIO 17 R40

PHY_RST ETH Reset and Status LEDs

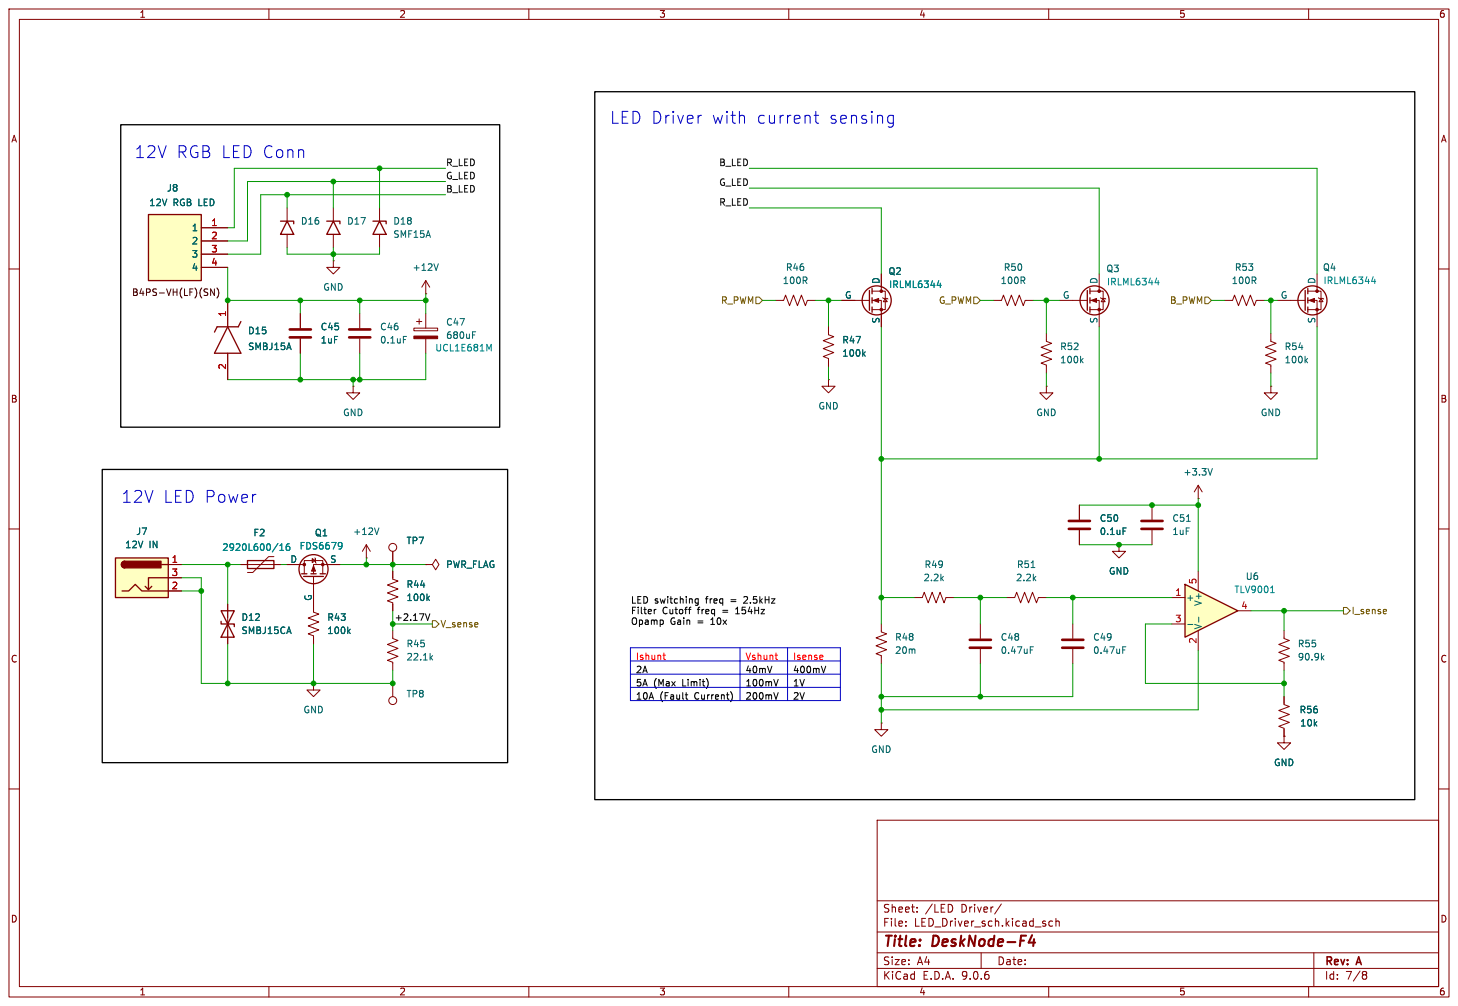
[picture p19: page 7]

LED Driver with current sensing

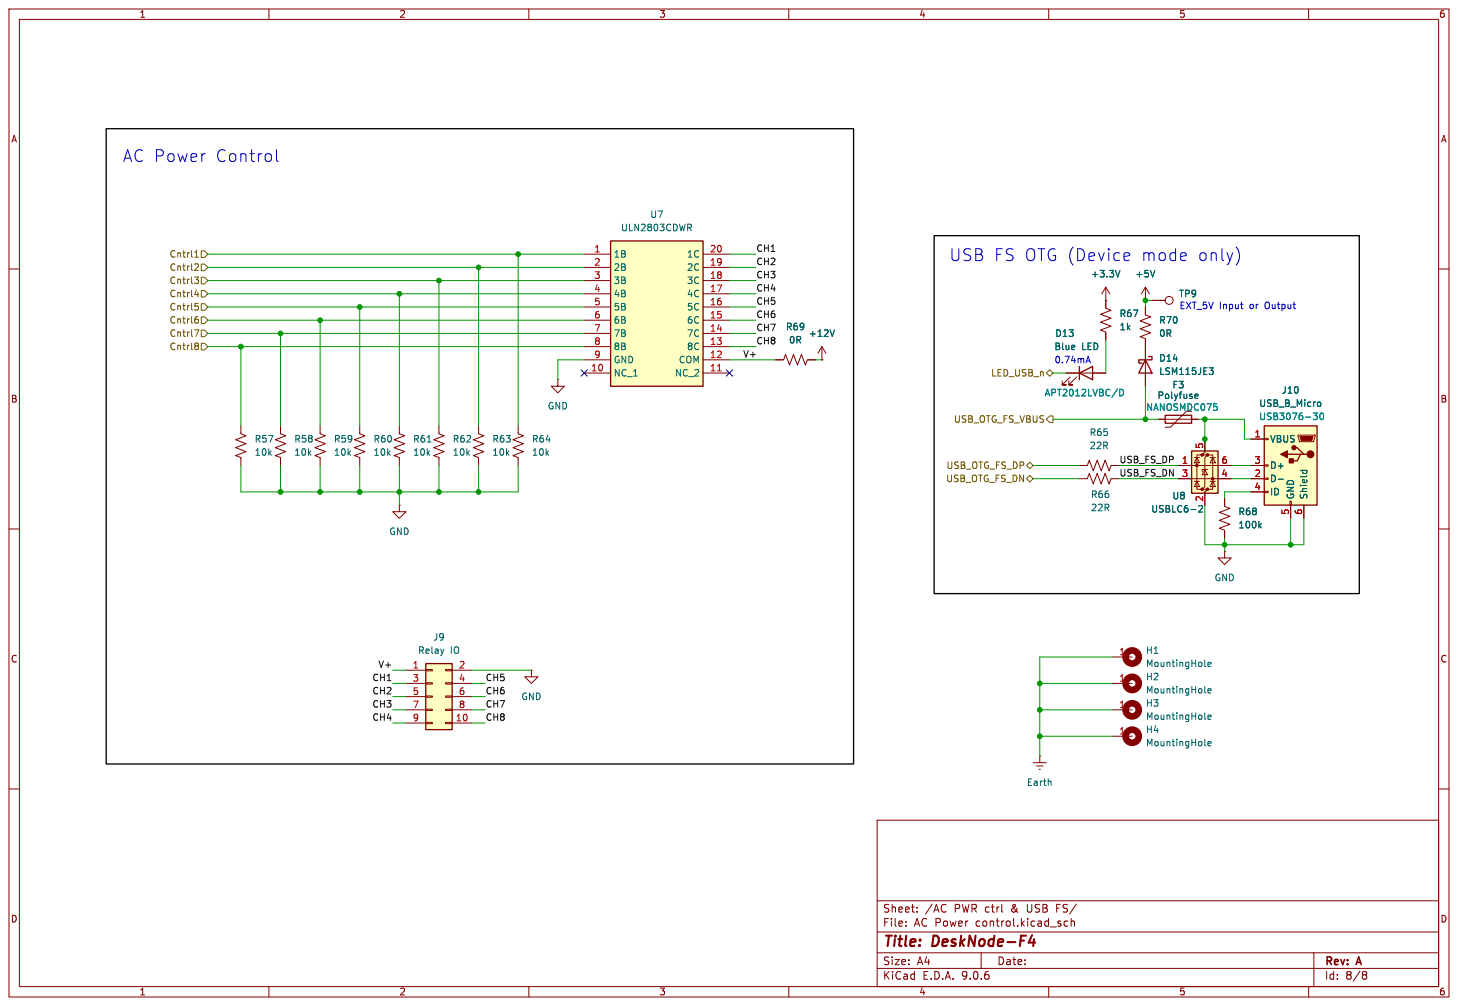
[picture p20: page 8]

USB FS OTG (Device mode only)

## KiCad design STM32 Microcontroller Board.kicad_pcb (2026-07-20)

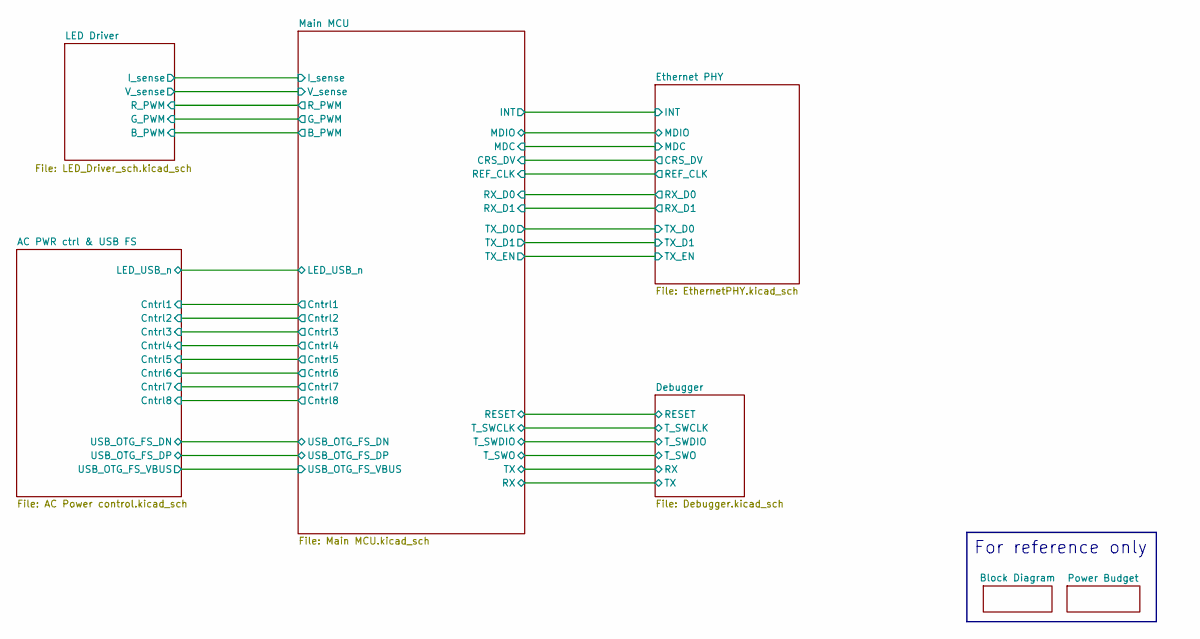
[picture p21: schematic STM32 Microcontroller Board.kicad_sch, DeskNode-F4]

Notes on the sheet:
For reference only

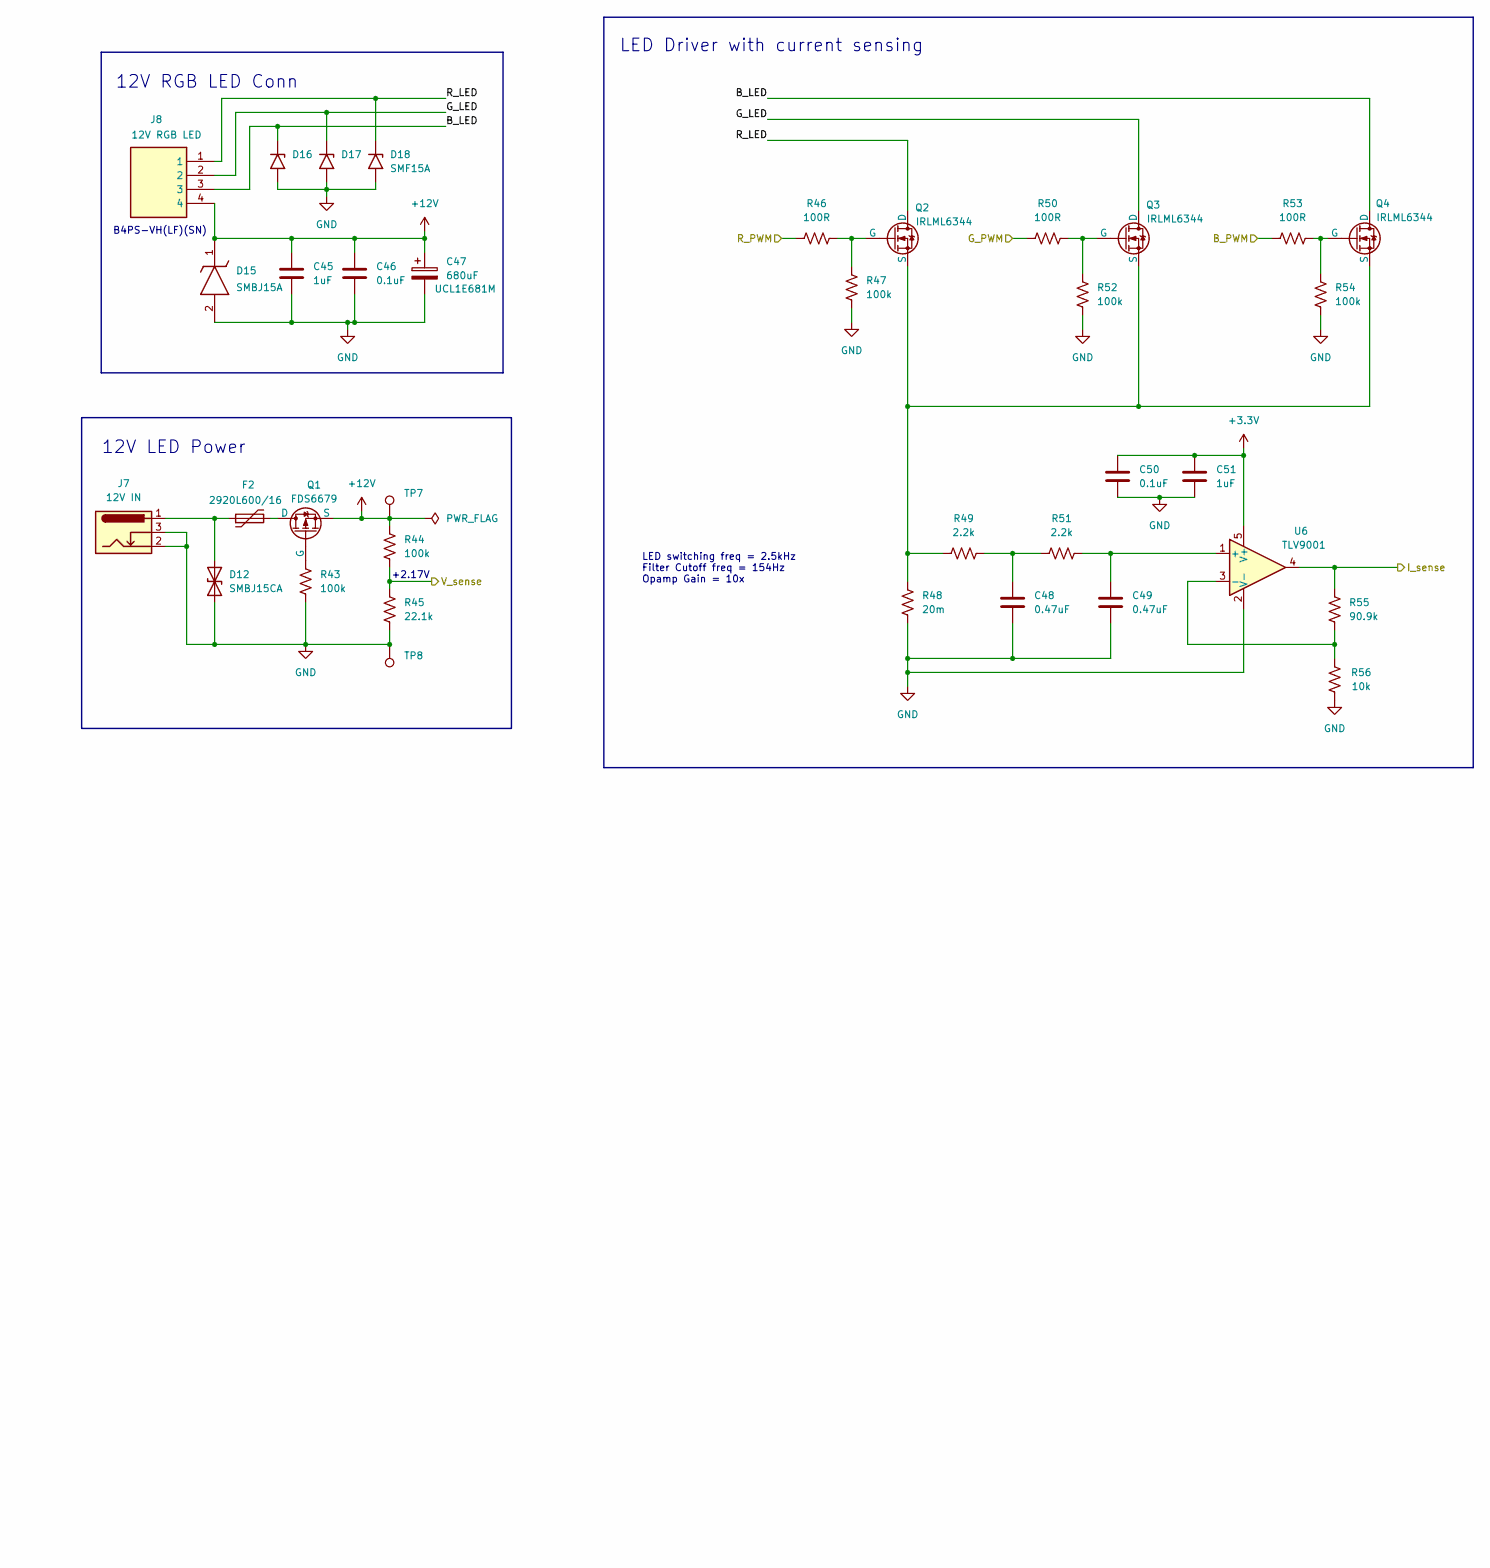
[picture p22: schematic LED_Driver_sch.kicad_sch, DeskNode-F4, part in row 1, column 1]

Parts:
C45: 1uF; C_0603_1608Metric; MPN CC0603KRX7R9BB105
C46: 0.1uF; C_0603_1608Metric; MPN C0603C104K5RACTU
C47: 680uF; UCL1E681MNL1GS; MPN UCL1E681MNL1GS
C48, C49: 0.47uF; C_0603_1608Metric; MPN CL10B474KA8NFNC
C50: 0.1uF; C_0402_1005Metric; MPN GRM155R71A104KA01D
C51: 1uF; C_0603_1608Metric; MPN CL10B105KP8NNNC
D12: SMBJ15CA; SMBJ15A; MPN SMBJ15CA
D15: SMBJ15A; Mouser Part Number 576-SMBJ15A
D16, D17, D18: SMF15A; D_SMF; MPN SMF15A
F2: Polyfuse; Fuse_2920_7451Metric; MPN 2920L600/16MR
J7: 12V IN; BarrelJack_Horizontal
J8: 12V RGB LED; B4PS-VH; Mouser Part Number 306-B4PS-VHLFSN
Q1: PMOS; SOIC-8_5.3x5.3mm_P1.27mm; Manufacturer_Part_Number FDS6679
Q2, Q3, Q4: NMOS; SOT-23; MPN IRLML6344TRPBF
R43, R44, R47, R52, R54: 100k; R_0603_1608Metric; MPN RC0603FR-07100KL
R45: 22.1k; R_0603_1608Metric; MPN RC0603FR-0722K1L
R46, R50, R53: 100R; R_0603_1608Metric; MPN RC0603FR-07100RL
R48: 20m; R_2512_6332Metric; MPN CRA2512-FZ-R020ELF
R49, R51: 2.2k; R_0603_1608Metric; MPN RC0603FR-072K2L
R55: 90.9k; R_0603_1608Metric; MPN RC0603FR-0790K9L
R56: 10k; R_0603_1608Metric; MPN RC0603FR-0710KL
TP7, TP8: TestPoint; TestPoint_Keystone_5000-5004_Miniature; MPN 5001
U6: TLV9001TIDCKR; SOT-353_SC-70-5; MPN TLV9001TIDCKR

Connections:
+3.3V: C50.1, C51.1, U6.5 (V+); also elsewhere on the board
+12V: C45.1, C46.1, C47.1, D15.1 (K), J8.4, Q1.2 (S), R44.1, TP7.1; also elsewhere on the board
/LED Driver/B_LED: D16.1 (A1), J8.3, Q4.1 (D)
/LED Driver/B_PWM: R53.1; also elsewhere on the board
/LED Driver/G_LED: D17.1 (A1), J8.2, Q3.1 (D)
/LED Driver/G_PWM: R50.1; also elsewhere on the board
/LED Driver/I_sense: R55.2, U6.4; also elsewhere on the board
/LED Driver/R_LED: D18.1 (A1), J8.1, Q2.1 (D)
/LED Driver/R_PWM: R46.1; also elsewhere on the board
/Main MCU/PB1: R44.2, R45.1; also elsewhere on the board
GND: C45.2, C46.2, C47.2, C48.2, C49.1, C50.2, C51.2, D12.1 (A1), D15.2 (A), D16.2 (A2), D17.2 (A2), D18.2 (A2), J7.2, J7.3, R43.2, R45.2, R47.2, R48.2, R52.2, R54.2, R56.1, TP8.1, U6.2 (V-); also elsewhere on the board
unnamed: C48.1, R49.2, R51.1
unnamed: D12.2 (A2), F2.1, J7.1
unnamed: F2.2, Q1.3 (D)
unnamed: Q1.1 (G), R43.1
unnamed: Q2.2 (G), R46.2, R47.1
unnamed: Q2.3 (S), Q3.3 (S), Q4.3 (S), R48.1, R49.1
unnamed: Q3.2 (G), R50.2, R52.1
unnamed: Q4.2 (G), R53.2, R54.1
unnamed: C49.2, R51.2, U6.1 (+)
unnamed: R55.1, R56.2, U6.3 (-)

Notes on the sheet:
+2.17V
LED switching freq = 2.5kHz Filter Cutoff freq = 154Hz Opamp Gain = 10x
12V LED Power
12V RGB LED Conn
LED Driver with current sensing
B4PS-VH(LF)(SN)

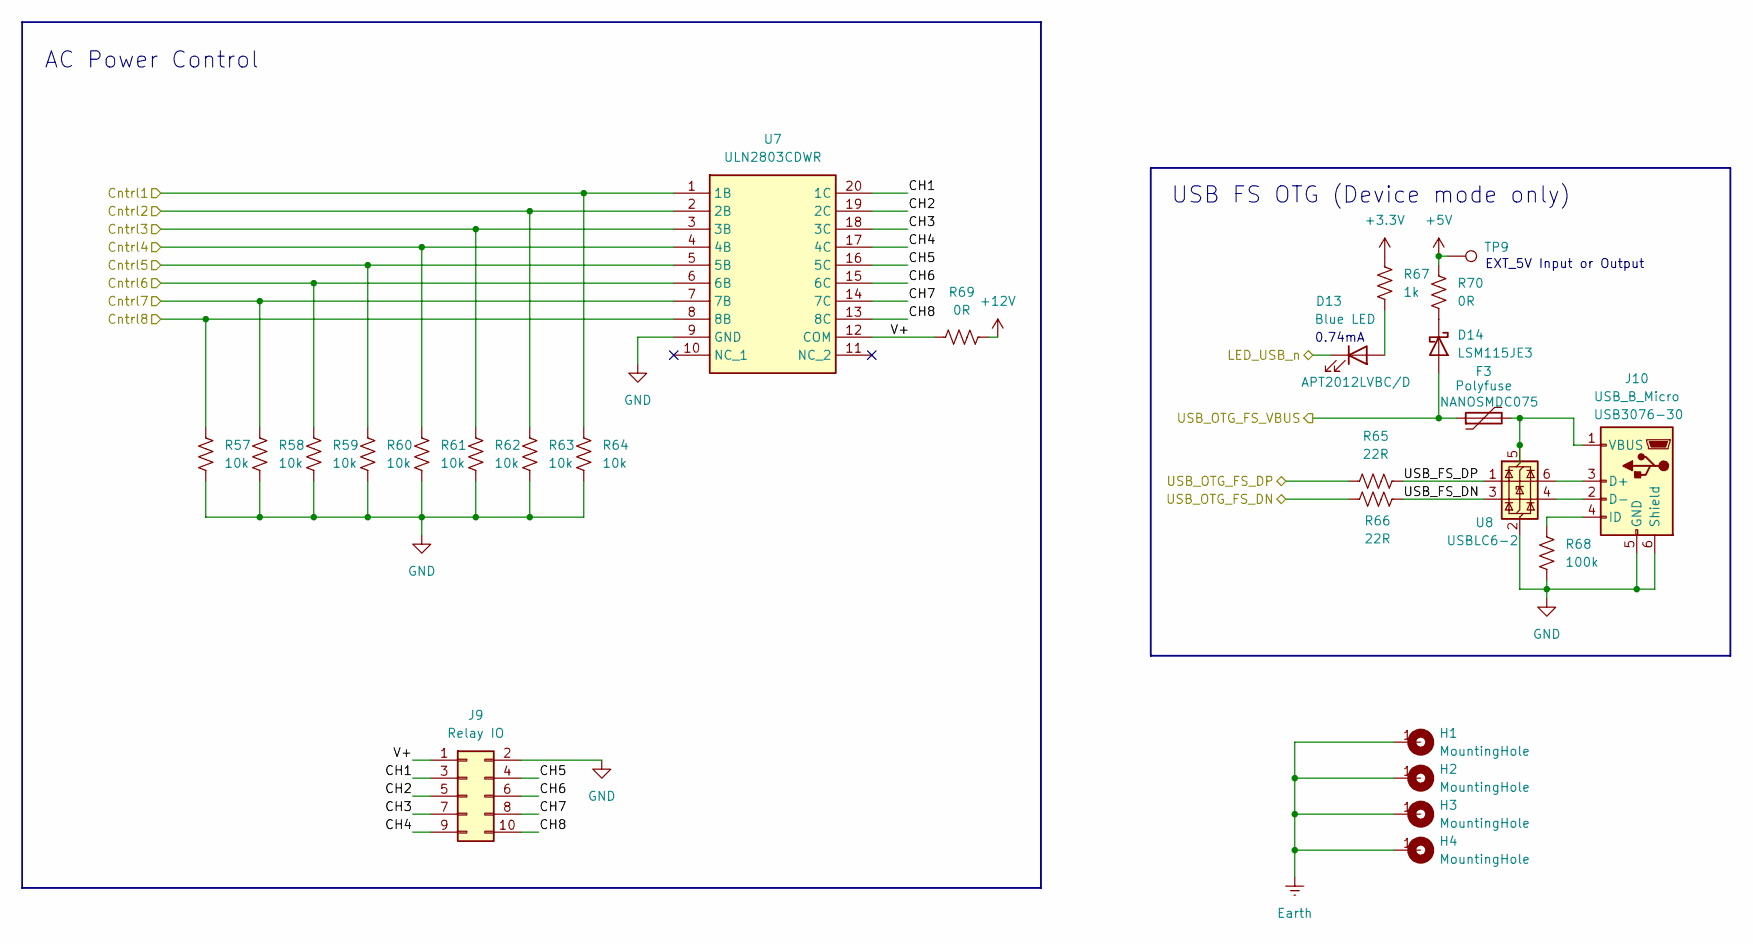
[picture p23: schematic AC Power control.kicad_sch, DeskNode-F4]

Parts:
D13: Blue LED; LED_0805_2012Metric; MPN APT2012LVBC/D
D14: LSM115JE3; D_SMB; MPN LSM115JE3-TR13
F3: Polyfuse; Fuse_1206_3216Metric; MPN NANOSMDC075F-2
H1, H2, H3, H4: MountingHole; MountingHole_3.2mm_M3_Pad
J9: Relay IO; PinHeader_2x05_P2.54mm_Vertical
J10: USB_B_Micro; USB_Micro-B_GCT_USB3076-30-A; MPN USB3076-30-A
R57, R58, R59, R60, R61, R62, R63, R64: 10k; R_0603_1608Metric; MPN RC0603FR-0710KL
R65, R66: 22R; R_0603_1608Metric; MPN RC0603FR-0722RL
R67: 1k; R_0603_1608Metric; MPN RC0603FR-071KL
R68: 100k; R_0603_1608Metric; MPN RC0603FR-07100KL
R69, R70: 0R; R_0603_1608Metric; MPN RC0603JR-070RL
TP9: TestPoint; TestPoint_Keystone_5000-5004_Miniature; MPN 5001
U7: ULN2803CDWR; Mouser Part Number 595-ULN2803CDWR
U8: USBLC6-2; SOT-23-6; MPN USBLC6-2SC6

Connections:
+3.3V: R67.1; also elsewhere on the board
+5V: R70.2, TP9.1; also elsewhere on the board
+12V: R69.2; also elsewhere on the board
/AC PWR ctrl & USB FS/CH1: J9.3, U7.20 (1C)
/AC PWR ctrl & USB FS/CH2: J9.5, U7.19 (2C)
/AC PWR ctrl & USB FS/CH3: J9.7, U7.18 (3C)
/AC PWR ctrl & USB FS/CH4: J9.9, U7.17 (4C)
/AC PWR ctrl & USB FS/CH5: J9.4, U7.16 (5C)
/AC PWR ctrl & USB FS/CH6: J9.6, U7.15 (6C)
/AC PWR ctrl & USB FS/CH7: J9.8, U7.14 (7C)
/AC PWR ctrl & USB FS/CH8: J9.10, U7.13 (8C)
/AC PWR ctrl & USB FS/Cntrl1: R64.1, U7.1 (1B); also elsewhere on the board
/AC PWR ctrl & USB FS/Cntrl2: R63.1, U7.2 (2B); also elsewhere on the board
/AC PWR ctrl & USB FS/Cntrl3: R62.1, U7.3 (3B); also elsewhere on the board
/AC PWR ctrl & USB FS/Cntrl4: R61.1, U7.4 (4B); also elsewhere on the board
/AC PWR ctrl & USB FS/Cntrl5: R60.1, U7.5 (5B); also elsewhere on the board
/AC PWR ctrl & USB FS/Cntrl6: R59.1, U7.6 (6B); also elsewhere on the board
/AC PWR ctrl & USB FS/Cntrl7: R58.1, U7.7 (7B); also elsewhere on the board
/AC PWR ctrl & USB FS/Cntrl8: R57.1, U7.8 (8B); also elsewhere on the board
/AC PWR ctrl & USB FS/LED_USB_n: D13.1 (K); also elsewhere on the board
/AC PWR ctrl & USB FS/USB_FS_DN: R66.2, U8.3 (I/O2)
/AC PWR ctrl & USB FS/USB_FS_DP: R65.1, U8.1 (I/O1)
/AC PWR ctrl & USB FS/USB_OTG_FS_DN: R66.1; also elsewhere on the board
/AC PWR ctrl & USB FS/USB_OTG_FS_DP: R65.2; also elsewhere on the board
/AC PWR ctrl & USB FS/USB_OTG_FS_VBUS: D14.2 (A), F3.1; also elsewhere on the board
/AC PWR ctrl & USB FS/V+: J9.1, R69.1, U7.12 (COM)
Earth: H1.1, H2.1, H3.1, H4.1; also elsewhere on the board
GND: J9.2, J10.5 (GND), J10.6 (Shield), R57.2, R58.2, R59.2, R60.2, R61.2, R62.2, R63.2, R64.2, R68.1, U7.9 (GND), U8.2 (GND); also elsewhere on the board
unnamed: D13.2 (A), R67.2
unnamed: D14.1 (K), R70.1
unnamed: J10.3 (D+), U8.6 (I/O1)
unnamed: J10.2 (D-), U8.4 (I/O2)
unnamed: J10.4 (ID), R68.2
unnamed: F3.2, J10.1 (VBUS), U8.5 (VBUS)

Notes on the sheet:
USB FS OTG (Device mode only)
EXT_5V Input or Output
AC Power Control
0.74mA

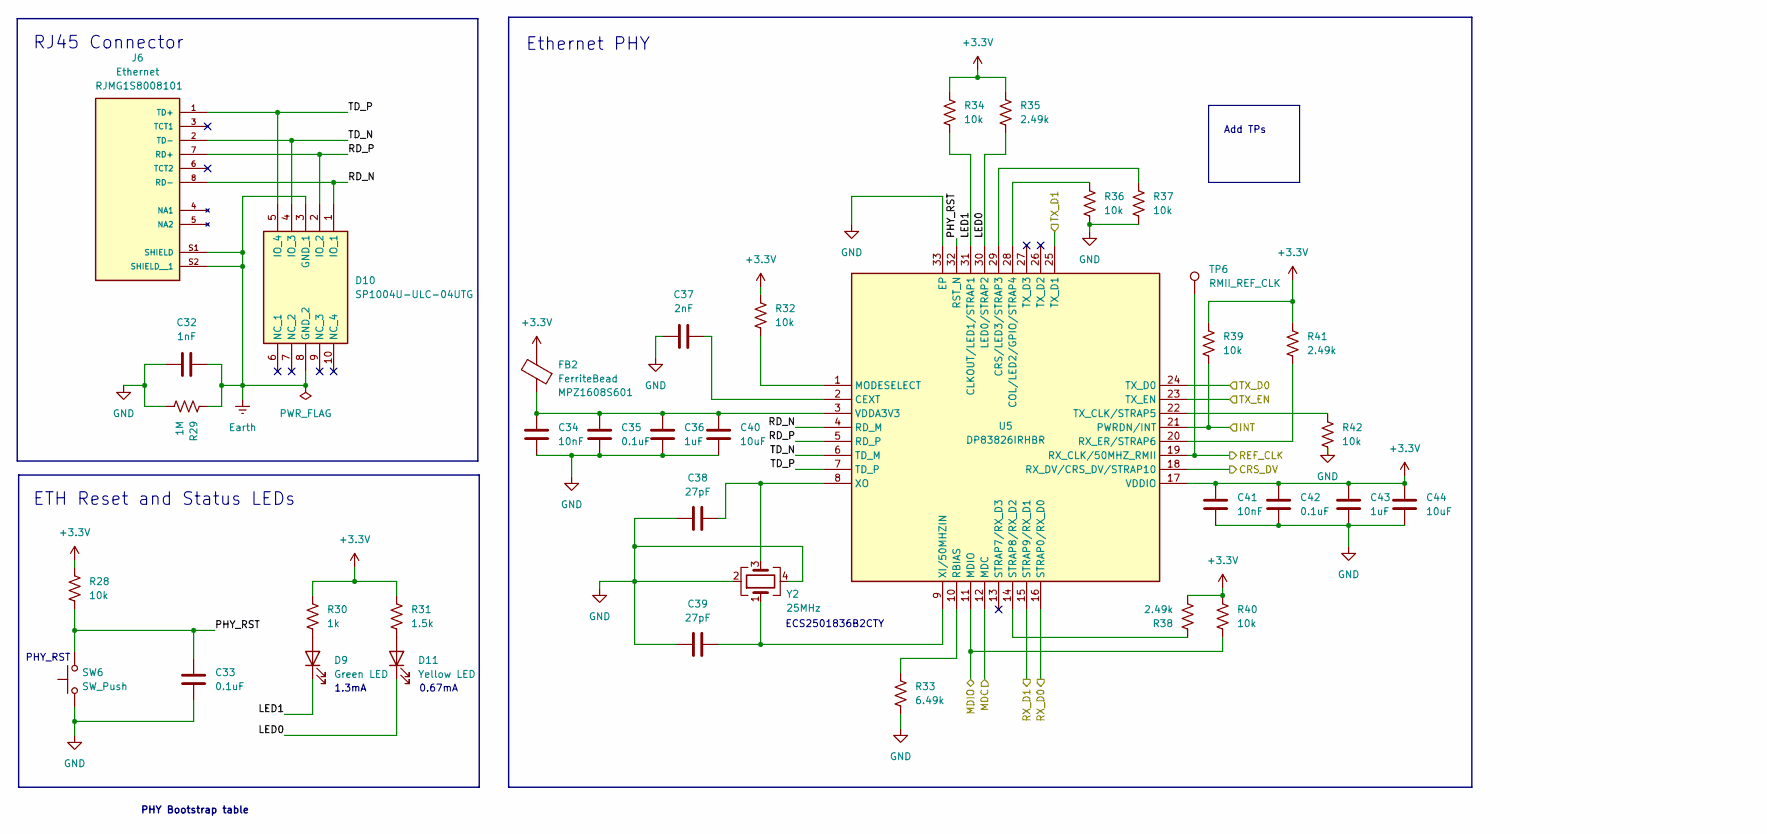
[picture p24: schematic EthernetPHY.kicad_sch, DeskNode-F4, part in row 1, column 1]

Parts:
C32: 1nF; C_1206_3216Metric; MPN CC1206KKX7RDBB102
C33, C35, C42: 0.1uF; C_0402_1005Metric; MPN GRM155R71A104KA01D
C34, C41: 10nF; C_0402_1005Metric; MPN GRM155R71E103KA01D
C36, C43: 1uF; C_0603_1608Metric; MPN CL10B105KP8NNNC
C37: 2nF; C_0603_1608Metric; MPN GRM1885C1H202JA01D
C38, C39: 27pF; C_0603_1608Metric; MPN CL10C270JB8NNNC
C40, C44: 10uF; C_0805_2012Metric; Manufacturer_Part_Number GRM21BR71A106KA73L
D9: Green LED; LED_0805_2012Metric; MPN APT2012CGCK
D10: SP1004U-ULC-04UTG; ESD8104MUTAG; MPN SP1004U-ULC-04UTG
D11: Yellow LED; LED_0805_2012Metric; MPN APT2012SYCK
FB2: FerriteBead; L_0603_1608Metric; MPN MPZ1608S601ATA00
J6: Ethernet; AMPHENOL_RJMG1S8008101BR; PARTREV A
R28, R32, R34, R36, R37, R39, R40, R42: 10k; R_0603_1608Metric; MPN RC0603FR-0710KL
R29: 1M; R_0603_1608Metric; MPN RC0603FR-071ML
R30: 1k; R_0603_1608Metric; MPN RC0603FR-071KL
R31: 1.5k; R_0603_1608Metric; MPN RC0603FR-071K5L
R33: 6.49k; R_0603_1608Metric; MPN RC0603FR-076K49L
R35, R38, R41: 2.49k; R_0603_1608Metric; MPN RC0603FR-072K49L
SW6: SW_Push; SW_SPST_PTS645Sx43SMTR92; MPN SWT0310-043016GSA
TP6: RMII_REF_CLK; TestPoint_Pad_D1.0mm
U5: DP83826IRHBR; QFN50P500X500X100-33N-D; Mouser Part Number 595-DP83826IRHBR
Y2: 25MHz; ECS2501836B2CTYTR; Mouser Part Number 520-250-18-36B2CTYTR

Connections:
+3.3V: C41.1, C42.1, C43.1, C44.1, FB2.2, R28.1, R30.1, R31.2, R32.1, R34.1, R35.1, R38.1, R39.1, R40.1, R41.1, U5.17 (VDDIO); also elsewhere on the board
/Ethernet PHY/CRS_DV: U5.18 (RX_DV/CRS_DV/STRAP10); also elsewhere on the board
/Ethernet PHY/INT: R39.2, U5.21 (PWRDN/INT); also elsewhere on the board
/Ethernet PHY/LED0: D11.1 (K), R35.2, U5.30 (LED0/STRAP2)
/Ethernet PHY/LED1: D9.1 (K), R34.2, U5.31 (CLKOUT/LED1/STRAP1)
/Ethernet PHY/MDC: U5.12 (MDC); also elsewhere on the board
/Ethernet PHY/MDIO: R40.2, U5.11 (MDIO); also elsewhere on the board
/Ethernet PHY/PHY_RST: C33.1, R28.2, SW6.2, U5.32 (RST_N)
/Ethernet PHY/RD_N: D10.1 (IO_1), J6.8 (RD-), U5.4 (RD_M)
/Ethernet PHY/RD_P: D10.2 (IO_2), J6.7 (RD+), U5.5 (RD_P)
/Ethernet PHY/REF_CLK: TP6.1, U5.19 (RX_CLK/50MHZ_RMII); also elsewhere on the board
/Ethernet PHY/RX_D0: U5.16 (STRAP0/RX_D0); also elsewhere on the board
/Ethernet PHY/RX_D1: U5.15 (STRAP9/RX_D1); also elsewhere on the board
/Ethernet PHY/TD_N: D10.4 (IO_3), J6.2 (TD-), U5.6 (TD_M)
/Ethernet PHY/TD_P: D10.5 (IO_4), J6.1 (TD+), U5.7 (TD_P)
/Ethernet PHY/TX_D0: U5.24 (TX_D0); also elsewhere on the board
/Ethernet PHY/TX_D1: U5.25 (TX_D1); also elsewhere on the board
/Ethernet PHY/TX_EN: U5.23 (TX_EN); also elsewhere on the board
Earth: C32.2, D10.3 (GND_1), D10.8 (GND_2), J6.S1 (SHIELD), J6.S2 (SHIELD__1), R29.2; also elsewhere on the board
GND: C32.1, C33.2, C34.2, C35.2, C36.2, C37.1, C38.1, C39.1, C40.2, C41.2, C42.2, C43.2, C44.2, R29.1, R33.1, R36.2, R37.2, R42.2, SW6.1, U5.33 (EP), Y2.2, Y2.4; also elsewhere on the board
unnamed: D9.2 (A), R30.2
unnamed: D11.2 (A), R31.1
unnamed: C37.2, U5.2 (CEXT)
unnamed: R36.1, U5.28 (COL/LED2/GPIO/STRAP4)
unnamed: R37.1, U5.29 (CRS/LED3/STRAP3)
unnamed: R32.2, U5.1 (MODESELECT)
unnamed: R33.2, U5.10 (RBIAS)
unnamed: R41.2, U5.20 (RX_ER/STRAP6)
unnamed: R38.2, U5.14 (STRAP8/RX_D2)
unnamed: R42.1, U5.22 (TX_CLK/STRAP5)
unnamed: C34.1, C35.1, C36.1, C40.1, FB2.1, U5.3 (VDDA3V3)
unnamed: C39.2, U5.9 (XI/50MHZIN), Y2.1
unnamed: C38.2, U5.8 (XO), Y2.3

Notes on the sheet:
0.67mA
Add TPs
Ethernet PHY
ECS2501836B2CTY
PHY Bootstrap table
RJ45 Connector
1.3mA
PHY_RST
ETH Reset and Status LEDs

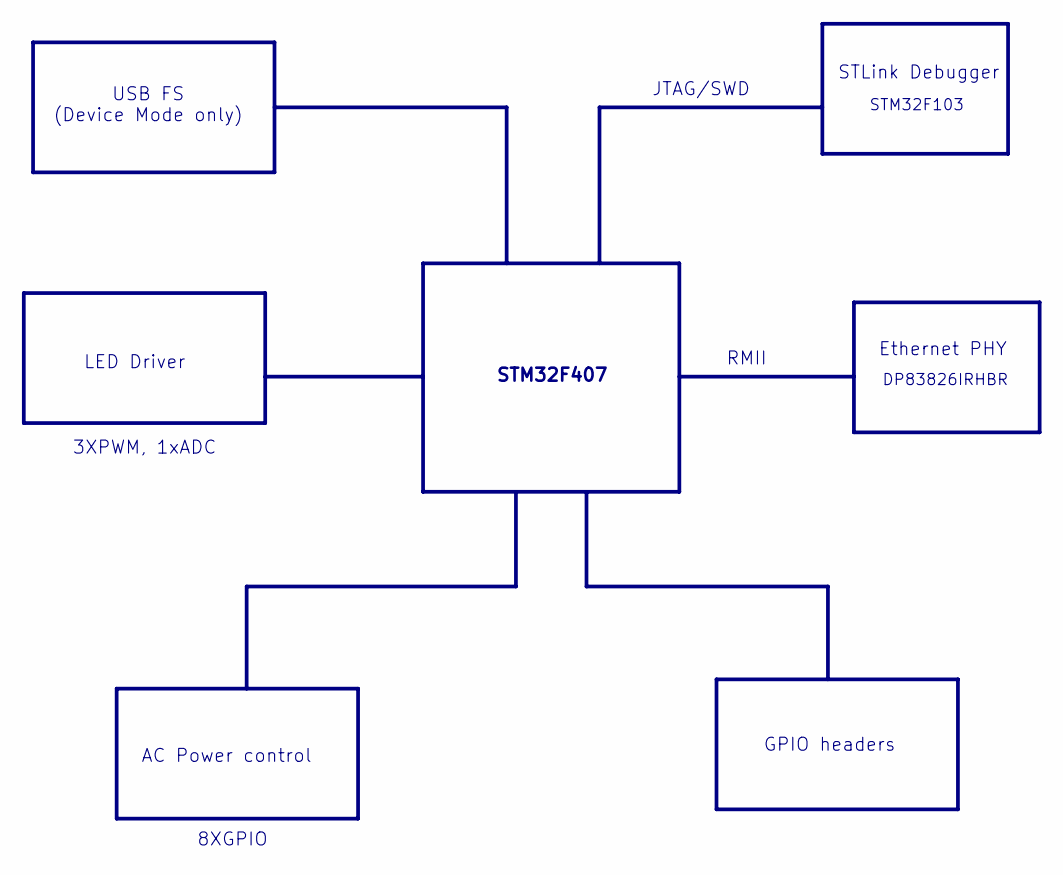
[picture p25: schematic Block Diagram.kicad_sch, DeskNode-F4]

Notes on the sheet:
DP83826IRHBR
STLink Debugger
LED Driver
JTAG/SWD
STM32F407
USB FS (Device Mode only)
GPIO headers
3XPWM, 1xADC
8XGPIO
STM32F103
Ethernet PHY
AC Power control
RMII

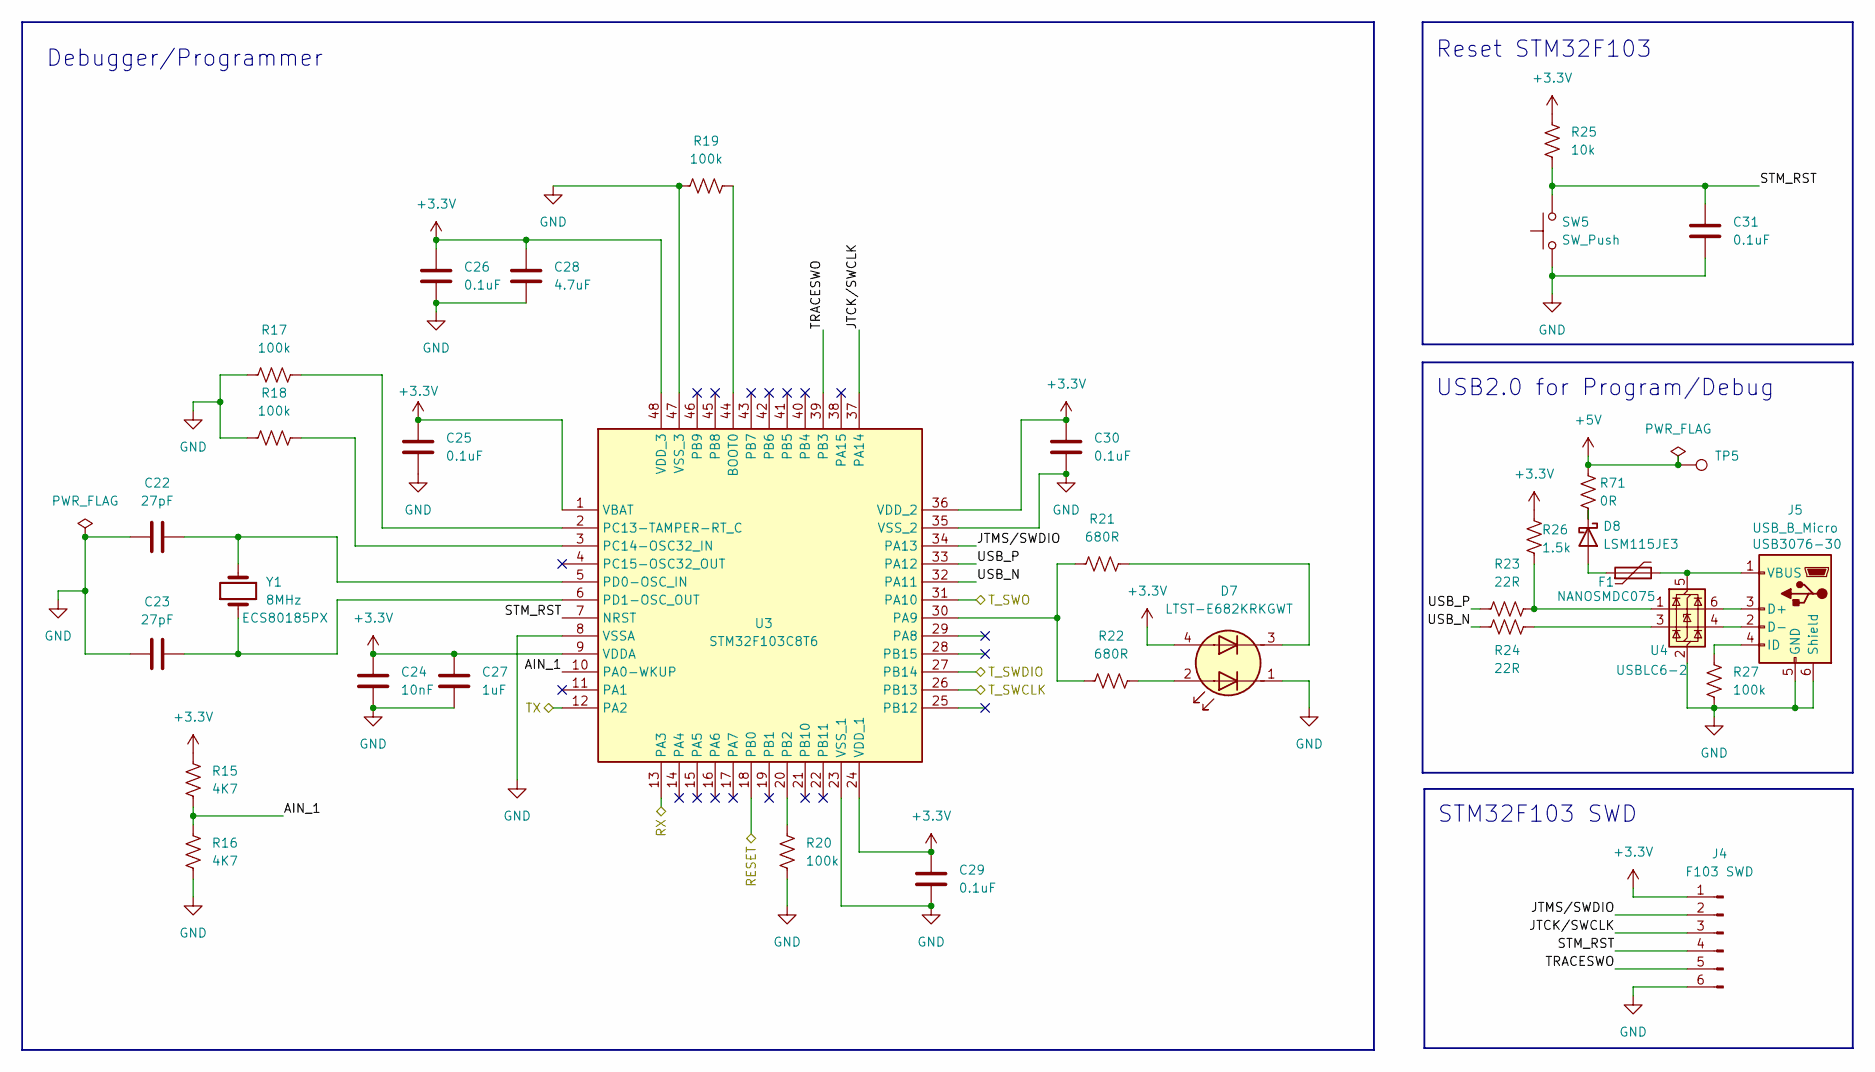
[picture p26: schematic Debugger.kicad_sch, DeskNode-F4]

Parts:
C22, C23: 27pF; C_0603_1608Metric; MPN CL10C270JB8NNNC
C24: 10nF; C_0402_1005Metric; MPN GRM155R71E103KA01D
C25, C26, C29, C30, C31: 0.1uF; C_0402_1005Metric; MPN GRM155R71A104KA01D
C27: 1uF; C_0603_1608Metric; MPN CL10B105KP8NNNC
C28: 4.7uF; C_0805_2012Metric; MPN GRM21BR71C475KE51L
D7: LTST-E682KRKGWT; LTSTE683RGBW; MPN LTST-E682KRKGWT
D8: LSM115JE3; D_SMB; MPN LSM115JE3-TR13
F1: Polyfuse; Fuse_1206_3216Metric; MPN NANOSMDC075F-2
J4: F103 SWD; PinHeader_1x06_P2.54mm_Vertical
J5: USB_B_Micro; USB_Micro-B_GCT_USB3076-30-A; MPN USB3076-30-A
R15, R16: 4K7; R_0603_1608Metric; MPN RC0603FR-074K7L
R17, R18, R19, R20, R27: 100k; R_0603_1608Metric; MPN RC0603FR-07100KL
R21, R22: 680R; R_0603_1608Metric; MPN RC0603FR-07680RL
R23, R24: 22R; R_0603_1608Metric; MPN RC0603FR-0722RL
R25: 10k; R_0603_1608Metric; MPN RC0603FR-0710KL
R26: 1.5k; R_0603_1608Metric; MPN RC0603FR-071K5L
R71: 0R; R_0603_1608Metric; MPN RC0603JR-070RL
SW5: SW_Push; SW_SPST_PTS645Sx43SMTR92; MPN SWT0310-043016GSA
TP5: TestPoint; TestPoint_Keystone_5000-5004_Miniature; MPN 5001
U3: STM32F103C8T6; QFP50P900X900X160-48N; Mouser Part Number 511-STM32F103C8T6
U4: USBLC6-2; SOT-23-6; MPN USBLC6-2SC6
Y1: 8MHz; Crystal_HC49-4H_Vertical; MPN ECS-80-18-5PX-TR

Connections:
+3.3V: C24.1, C25.1, C26.1, C27.1, C28.1, C29.1, C30.1, D7.4 (A2), J4.1, R15.2, R25.1, R26.1, U3.1 (VBAT), U3.9 (VDDA), U3.24 (VDD_1), U3.36 (VDD_2), U3.48 (VDD_3); also elsewhere on the board
+5V: R71.2, TP5.1; also elsewhere on the board
/Debugger/AIN_1: R15.1, R16.2, U3.10 (PA0-WKUP)
/Debugger/JTCK/SWCLK: J4.3, U3.37 (PA14)
/Debugger/JTMS/SWDIO: J4.2, U3.34 (PA13)
/Debugger/RX: U3.13 (PA3); also elsewhere on the board
/Debugger/STM_RST: C31.1, J4.4, R25.2, SW5.2, U3.7 (NRST)
/Debugger/TRACESWO: J4.5, U3.39 (PB3)
/Debugger/TX: U3.12 (PA2); also elsewhere on the board
/Debugger/USB_N: R24.1, U3.32 (PA11)
/Debugger/USB_P: R23.2, U3.33 (PA12)
/Main MCU/RESET: U3.18 (PB0); also elsewhere on the board
/Main MCU/T_SWCLK: U3.26 (PB13); also elsewhere on the board
/Main MCU/T_SWDIO: U3.27 (PB14); also elsewhere on the board
/Main MCU/T_SWO: U3.31 (PA10); also elsewhere on the board
GND: C22.1, C23.1, C24.2, C25.2, C26.2, C27.2, C28.2, C29.2, C30.2, C31.2, D7.1 (K1), J4.6, J5.5 (GND), J5.6 (Shield), R16.1, R17.1, R18.1, R19.1, R20.2, R27.1, SW5.1, U3.8 (VSSA), U3.23 (VSS_1), U3.35 (VSS_2), U3.47 (VSS_3), U4.2 (GND); also elsewhere on the board
unnamed: D7.2 (A1), R22.2
unnamed: D7.3 (K2), R21.2
unnamed: D8.2 (A), F1.1
unnamed: D8.1 (K), R71.1
unnamed: J5.3 (D+), U4.6 (I/O1)
unnamed: J5.2 (D-), U4.4 (I/O2)
unnamed: J5.4 (ID), R27.2
unnamed: F1.2, J5.1 (VBUS), U4.5 (VBUS)
unnamed: R23.1, R26.2, U4.1 (I/O1)
unnamed: R24.2, U4.3 (I/O2)
unnamed: R19.2, U3.44 (BOOT0)
unnamed: R21.1, R22.1, U3.30 (PA9)
unnamed: R20.1, U3.20 (PB2)
unnamed: R17.2, U3.2 (PC13-TAMPER-RT_C)
unnamed: R18.2, U3.3 (PC14-OSC32_IN)
unnamed: C22.2, U3.5 (PD0-OSC_IN), Y1.2
unnamed: C23.2, U3.6 (PD1-OSC_OUT), Y1.1

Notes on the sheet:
STM32F103 SWD
USB2.0 for Program/Debug
Reset STM32F103
Debugger/Programmer

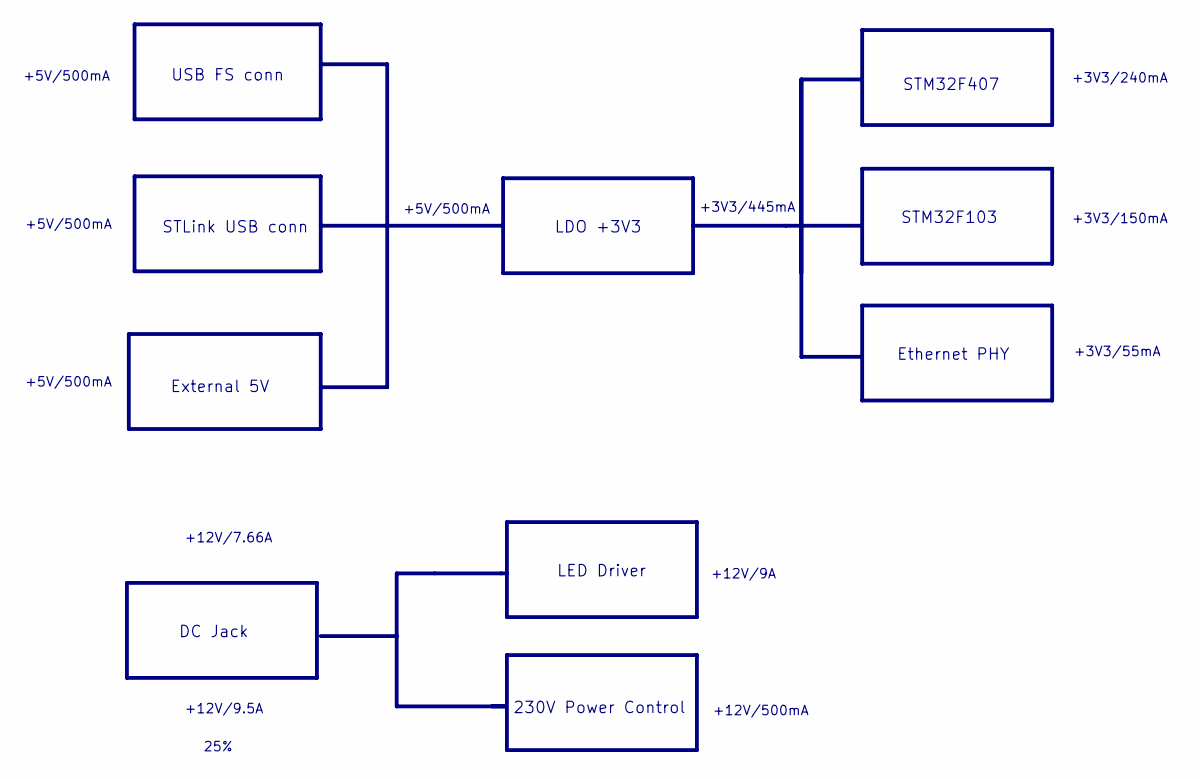
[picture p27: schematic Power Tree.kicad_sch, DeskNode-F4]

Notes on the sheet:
+12V/9A
External 5V
+5V/500mA
USB FS conn
230V Power Control
+12V/9.5A
LED Driver
+3V3/55mA
STM32F103
Ethernet PHY
+3V3/150mA
DC Jack
+12V/7.66A
25%
STM32F407
+12V/500mA
+3V3/240mA
LDO +3V3
+3V3/445mA
STLink USB conn

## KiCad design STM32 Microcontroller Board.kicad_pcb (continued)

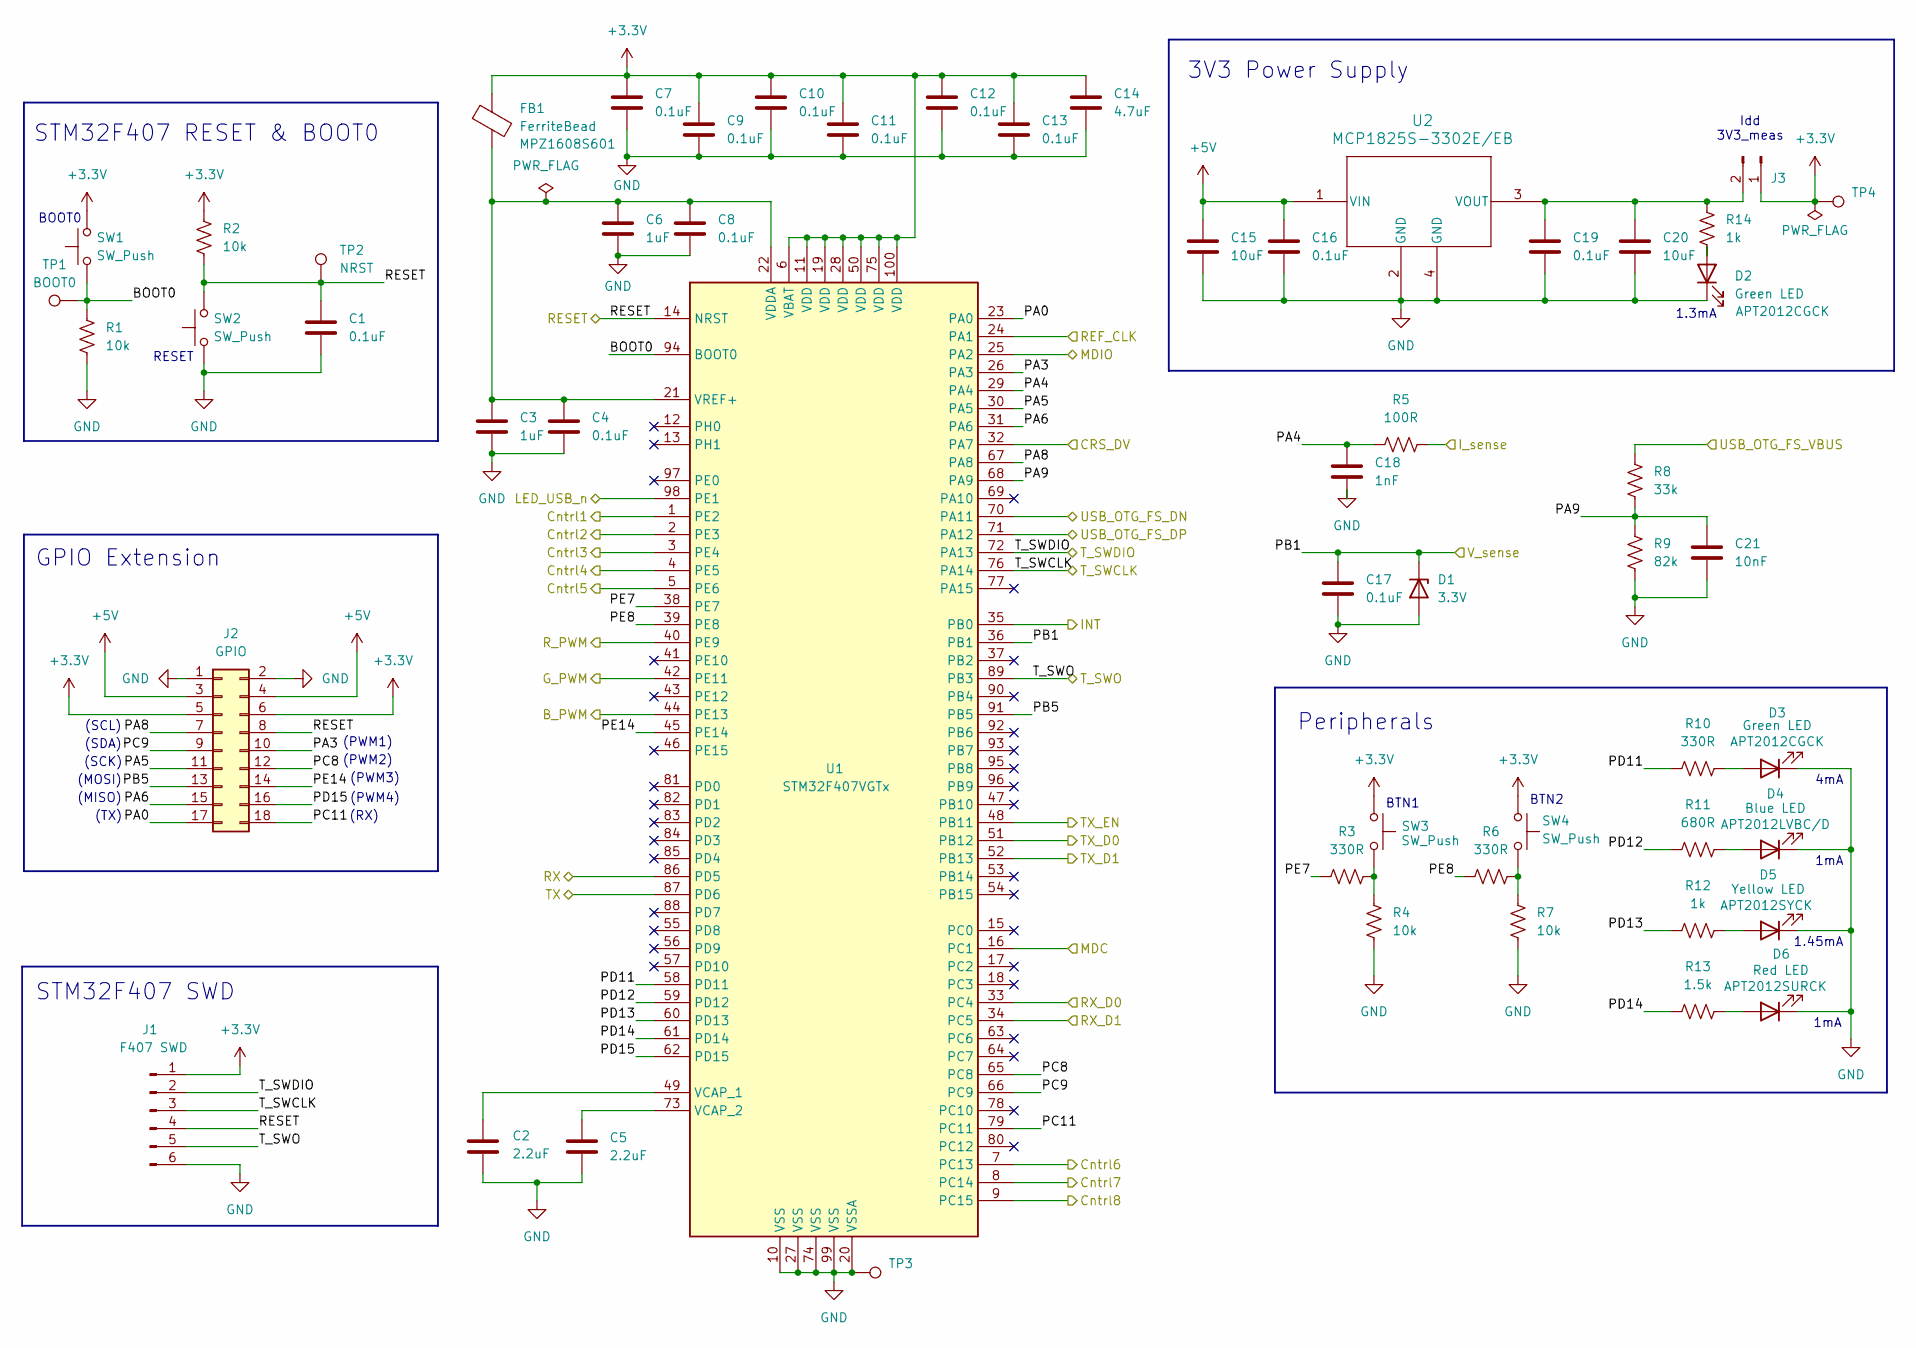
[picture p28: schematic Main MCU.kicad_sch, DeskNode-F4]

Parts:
C1, C4, C7, C8, C9, C10, C11, C12, C13, C16, C17, C19: 0.1uF; C_0402_1005Metric; MPN GRM155R71A104KA01D
C2, C5: 2.2uF; C_0603_1608Metric; MPN CL10B225KP8NNNC
C3, C6: 1uF; C_0603_1608Metric; MPN CL10B105KP8NNNC
C14: 4.7uF; C_0805_2012Metric; MPN GRM21BR71C475KE51L
C15, C20: 10uF; C_0805_2012Metric; MPN CL21B106KOQNNNE
C18: 1nF; C_0603_1608Metric; MPN C0603C102K4RACTU
C21: 10nF; C_0402_1005Metric; MPN GRM155R71E103KA01D
D1: 3.3V; D_SOD-323F; MPN MM3Z3V3T1G
D2, D3: Green LED; LED_0805_2012Metric; MPN APT2012CGCK
D4: Blue LED; LED_0805_2012Metric; MPN APT2012LVBC/D
D5: Yellow LED; LED_0805_2012Metric; MPN APT2012SYCK
D6: Red LED; LED_0805_2012Metric; MPN APT2012SURCK
FB1: FerriteBead; L_0603_1608Metric; MPN MPZ1608S601ATA00
J1: F407 SWD; PinHeader_1x06_P2.54mm_Vertical
J2: GPIO; PinHeader_2x09_P2.54mm_Vertical
J3: Conn_01x02_Pin; PinHeader_1x02_P2.54mm_Vertical
R1, R2, R4, R7: 10k; R_0603_1608Metric; MPN RC0603FR-0710KL
R3, R6, R10: 330R; R_0603_1608Metric; MPN RC0603FR-07330RL
R5: 100R; R_0603_1608Metric; MPN RC0603FR-07100RL
R8: 33k; R_0603_1608Metric; MPN RC0603FR-0733KL
R9: 82k; R_0603_1608Metric; MPN RC0603FR-0782KL
R11: 680R; R_0603_1608Metric; MPN RC0603FR-07680RL
R12, R14: 1k; R_0603_1608Metric; MPN RC0603FR-071KL
R13: 1.5k; R_0603_1608Metric; MPN RC0603FR-071K5L
SW1, SW2, SW3, SW4: SW_Push; SW_SPST_PTS645Sx43SMTR92; MPN SWT0310-043016GSA
TP1: BOOT0; TestPoint_Pad_D1.0mm
TP2: NRST; TestPoint_Pad_D1.0mm
TP3, TP4: TestPoint; TestPoint_Keystone_5000-5004_Miniature; MPN 5001
U1: STM32F407VGTx; LQFP-100_14x14mm_P0.5mm; MPN STM32F407VGT6
U2: MCP1825S-3302E/EB; DDPAK3_MC_MCH-L; MPN MCP1825S-3302E/EB

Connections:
+3.3V: C7.1, C9.1, C10.1, C11.1, C12.1, C13.1, C14.1, FB1.2, J1.1, J2.5, J2.6, J3.1, R2.1, SW1.2, SW3.1, SW4.1, TP4.1, U1.6 (VBAT), U1.11 (VDD), U1.19 (VDD), U1.28 (VDD), U1.50 (VDD), U1.75 (VDD), U1.100 (VDD); also elsewhere on the board
+5V: C15.1, C16.1, J2.3, J2.4, U2.1 (VIN); also elsewhere on the board
/AC PWR ctrl & USB FS/Cntrl1: U1.1 (PE2); also elsewhere on the board
/AC PWR ctrl & USB FS/Cntrl2: U1.2 (PE3); also elsewhere on the board
/AC PWR ctrl & USB FS/Cntrl3: U1.3 (PE4); also elsewhere on the board
/AC PWR ctrl & USB FS/Cntrl4: U1.4 (PE5); also elsewhere on the board
/AC PWR ctrl & USB FS/Cntrl5: U1.5 (PE6); also elsewhere on the board
/AC PWR ctrl & USB FS/Cntrl6: U1.7 (PC13); also elsewhere on the board
/AC PWR ctrl & USB FS/Cntrl7: U1.8 (PC14); also elsewhere on the board
/AC PWR ctrl & USB FS/Cntrl8: U1.9 (PC15); also elsewhere on the board
/AC PWR ctrl & USB FS/LED_USB_n: U1.98 (PE1); also elsewhere on the board
/AC PWR ctrl & USB FS/USB_OTG_FS_DN: U1.70 (PA11); also elsewhere on the board
/AC PWR ctrl & USB FS/USB_OTG_FS_DP: U1.71 (PA12); also elsewhere on the board
/AC PWR ctrl & USB FS/USB_OTG_FS_VBUS: R8.1; also elsewhere on the board
/Debugger/RX: U1.87 (PD6); also elsewhere on the board
/Debugger/TX: U1.86 (PD5); also elsewhere on the board
/Ethernet PHY/CRS_DV: U1.32 (PA7); also elsewhere on the board
/Ethernet PHY/INT: U1.35 (PB0); also elsewhere on the board
/Ethernet PHY/MDC: U1.16 (PC1); also elsewhere on the board
/Ethernet PHY/MDIO: U1.25 (PA2); also elsewhere on the board
/Ethernet PHY/REF_CLK: U1.24 (PA1); also elsewhere on the board
/Ethernet PHY/RX_D0: U1.33 (PC4); also elsewhere on the board
/Ethernet PHY/RX_D1: U1.34 (PC5); also elsewhere on the board
/Ethernet PHY/TX_D0: U1.51 (PB12); also elsewhere on the board
/Ethernet PHY/TX_D1: U1.52 (PB13); also elsewhere on the board
/Ethernet PHY/TX_EN: U1.48 (PB11); also elsewhere on the board
/LED Driver/B_PWM: U1.44 (PE13); also elsewhere on the board
/LED Driver/G_PWM: U1.42 (PE11); also elsewhere on the board
/LED Driver/I_sense: R5.2; also elsewhere on the board
/LED Driver/R_PWM: U1.40 (PE9); also elsewhere on the board
/Main MCU/BOOT0: R1.1, SW1.1, TP1.1, U1.94 (BOOT0)
/Main MCU/PA0: J2.17, U1.23 (PA0)
/Main MCU/PA3: J2.10, U1.26 (PA3)
/Main MCU/PA4: C18.1, R5.1, U1.29 (PA4)
/Main MCU/PA5: J2.11, U1.30 (PA5)
/Main MCU/PA6: J2.15, U1.31 (PA6)
/Main MCU/PA8: J2.7, U1.67 (PA8)
/Main MCU/PA9: C21.1, R8.2, R9.1, U1.68 (PA9)
/Main MCU/PB1: C17.1, D1.1 (K), U1.36 (PB1); also elsewhere on the board
/Main MCU/PB5: J2.13, U1.91 (PB5)
/Main MCU/PC8: J2.12, U1.65 (PC8)
/Main MCU/PC9: J2.9, U1.66 (PC9)
/Main MCU/PC11: J2.18, U1.79 (PC11)
/Main MCU/PD11: R10.1, U1.58 (PD11)
/Main MCU/PD12: R11.1, U1.59 (PD12)
/Main MCU/PD13: R12.1, U1.60 (PD13)
/Main MCU/PD14: R13.1, U1.61 (PD14)
/Main MCU/PD15: J2.16, U1.62 (PD15)
/Main MCU/PE7: R3.1, U1.38 (PE7)
/Main MCU/PE8: R6.1, U1.39 (PE8)
/Main MCU/PE14: J2.14, U1.45 (PE14)
/Main MCU/RESET: C1.1, J1.4, J2.8, R2.2, SW2.2, TP2.1, U1.14 (NRST); also elsewhere on the board
/Main MCU/T_SWCLK: J1.3, U1.76 (PA14); also elsewhere on the board
/Main MCU/T_SWDIO: J1.2, U1.72 (PA13); also elsewhere on the board
/Main MCU/T_SWO: J1.5, U1.89 (PB3); also elsewhere on the board
GND: C1.2, C2.2, C3.2, C4.2, C5.2, C6.2, C7.2, C8.2, C9.2, C10.2, C11.2, C12.2, C13.2, C14.2, C15.2, C16.2, C17.2, C18.2, C19.2, C20.2, C21.2, D1.2 (A), D2.1 (K), D3.1 (K), D4.1 (K), D5.1 (K), D6.1 (K), J1.6, J2.1, J2.2, R1.2, R4.2, R7.2, R9.2, SW2.1, TP3.1, U1.10 (VSS), U1.20 (VSSA), U1.27 (VSS), U1.74 (VSS), U1.99 (VSS), U2.2 (GND), U2.4 (GND); also elsewhere on the board
unnamed: D2.2 (A), R14.2
unnamed: D3.2 (A), R10.2
unnamed: D4.2 (A), R11.2
unnamed: D5.2 (A), R12.2
unnamed: D6.2 (A), R13.2
unnamed: C19.1, C20.1, J3.2, R14.1, U2.3 (VOUT)
unnamed: R3.2, R4.1, SW3.2
unnamed: R6.2, R7.1, SW4.2
unnamed: C2.1, U1.49 (VCAP_1)
unnamed: C5.1, U1.73 (VCAP_2)
unnamed: C3.1, C4.1, C6.1, C8.1, FB1.1, U1.21 (VREF+), U1.22 (VDDA)

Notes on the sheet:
(SCL)
(PWM3)
1mA
(RX)
BTN1
(MISO)
STM32F407 RESET & BOOT0
BOOT0
(TX)
STM32F407 SWD
(PWM2)
1.45mA
Idd 3V3_meas
3V3 Power Supply
4mA
1.3mA
(PWM1)
(PWM4)
RESET
(SDA)
(SCK)
GPIO Extension
(MOSI)
Peripherals
BTN2

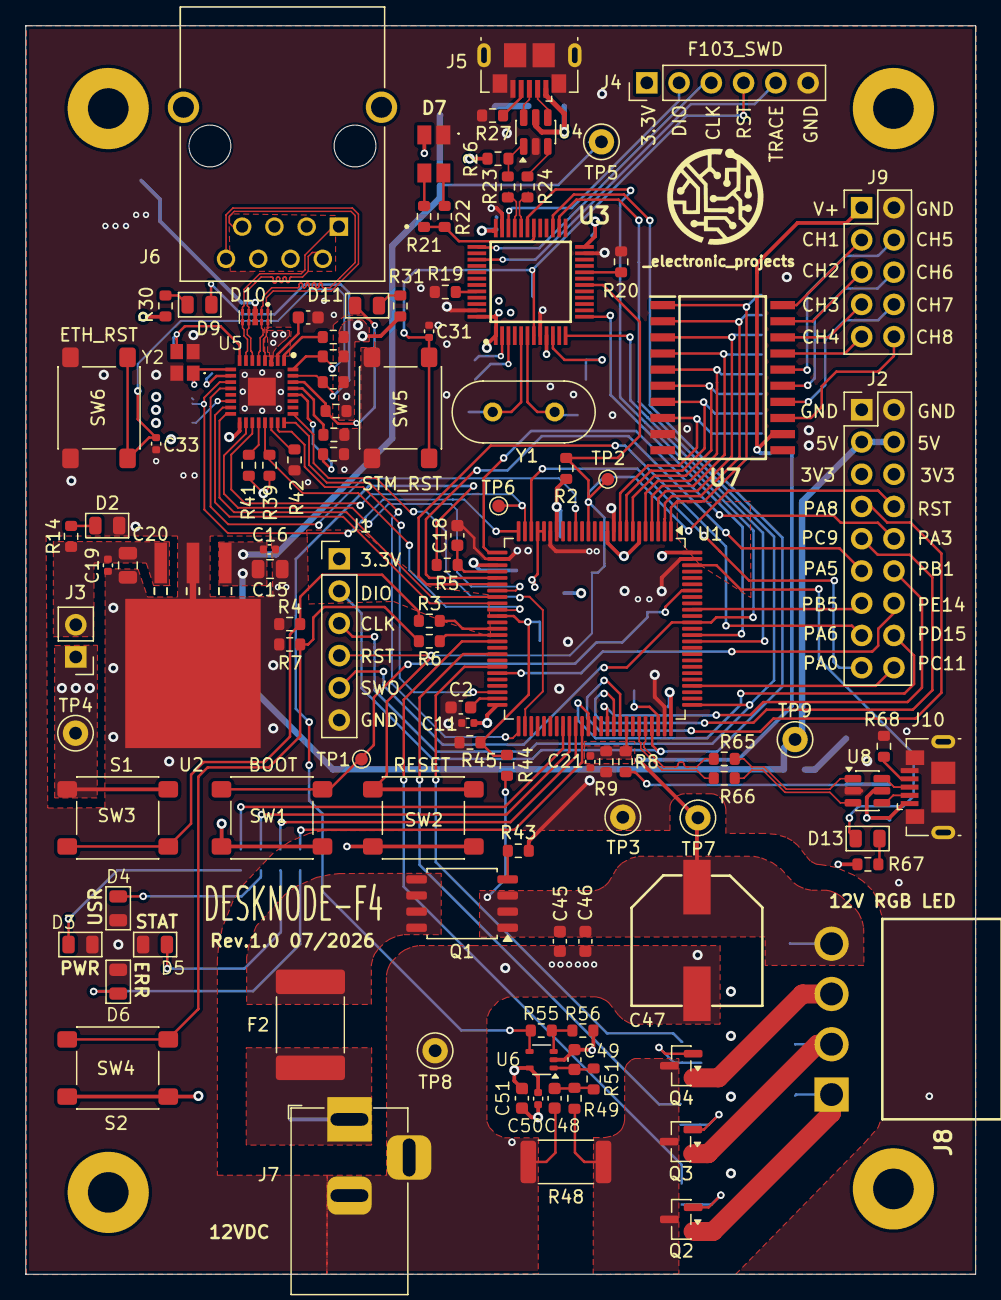
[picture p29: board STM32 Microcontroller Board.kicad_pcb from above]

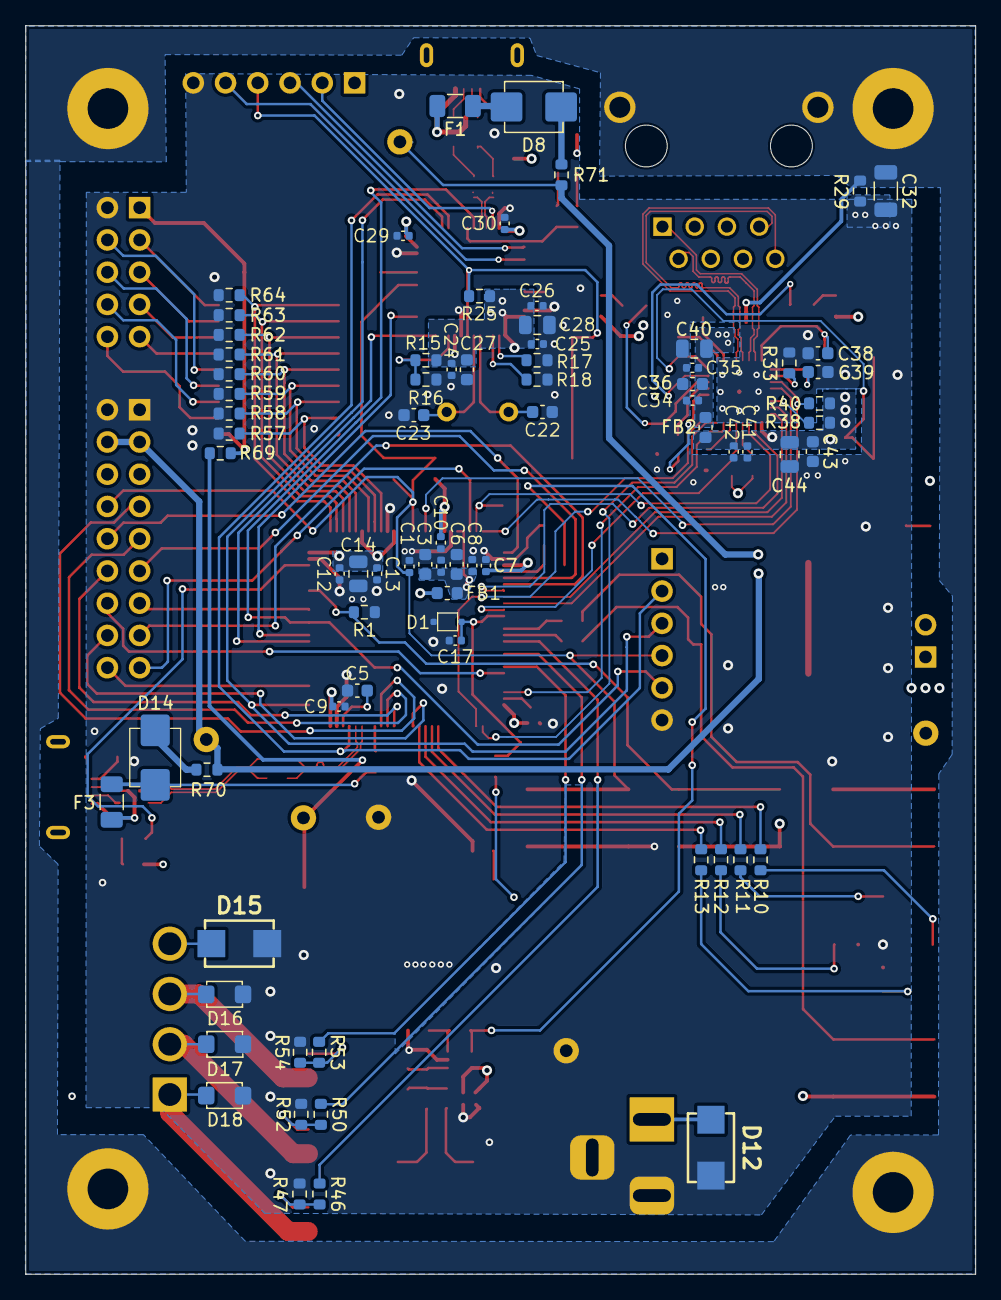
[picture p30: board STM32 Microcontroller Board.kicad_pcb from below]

Board: 4 copper layers, 74.8 x 98.3 mm, 188 parts (76 on the bottom side), 143 nets.

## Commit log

2026-04-16 Initial commit of KiCad project
    [AC Power control.kicad_sch, B4PS-VH_LF__SN_.stp, Block Diagram.kicad_sch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]
2026-05-11 Your descriptive message here
    [Main MCU.kicad_sch, Power.kicad_sch, STM32 Microcontroller Board.kicad_sch]
2026-05-13 Added 3V3 Power Supply
    [MCP1825S-3302EEB.step, Main MCU.kicad_sch]
2026-05-14 MCU power supplied
    [Main MCU.kicad_sch]
2026-05-15 Added user buttons and boot config
    [Main MCU.kicad_sch, Power.kicad_sch]
2026-05-21 Updated the root schematic page
    [Main MCU.kicad_sch, STM32 Microcontroller Board.kicad_sch]
2026-05-24 Done ERC + Documentation
    [AC Power control.kicad_sch, Debugger.kicad_sch, EthernetPHY.kicad_sch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]
2026-05-31 Initial Review Changes
    [AC Power control.kicad_sch, Block Diagram.kicad_sch, Debugger.kicad_sch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]
2026-06-08 MPNs updated
    [2920L600_24SLER.stp, AC Power control.kicad_sch, Debugger.kicad_sch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]
2026-06-11 Layout placement
    [AC Power control.kicad_sch, Debugger.kicad_sch, EthernetPHY.kicad_sch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]
2026-06-23 Layout Routing
    [AC Power control.kicad_sch, Debugger.kicad_sch, EthernetPHY.kicad_sch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]
2026-06-24 Layout - 12V Power path
    [AC Power control.kicad_sch, Debugger.kicad_sch, EthernetPHY.kicad_sch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]
2026-06-24 Updated layout
    [STM32 Microcontroller Board.kicad_pcb]
2026-06-25 12V i/p FIlter caps removed
    [LED_Driver_sch.kicad_sch, STM32 Microcontroller Board.kicad_pcb]
2026-06-27 Layout complete with DRC resolution
    [STM32 Microcontroller Board.kicad_pcb]
2026-06-28 Review files
    [AC Power control.kicad_sch, Block Diagram.kicad_sch, Debugger.kicad_sch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]
2026-07-12 Alternate MPNs added
    [AC Power control.kicad_sch, Debugger.kicad_sch, EthernetPHY.kicad_sch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]
2026-07-12 SV's comments
    [Debugger.kicad_sch, EthernetPHY.kicad_sch, LED_Driver_sch.kicad_sch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]
2026-07-20 All comments addressed
    [AC Power control.kicad_sch, Debugger.kicad_sch, EthernetPHY.kicad_sch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]
